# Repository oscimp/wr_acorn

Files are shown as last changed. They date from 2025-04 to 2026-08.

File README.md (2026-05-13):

# White Rabbit on general purpose FPGA boards (without the dedicated external oscillators)

Based on the original contribution by <a href="https://www.missinglinkelectronics.com/wp-content/uploads/2024/03/MLE-Light-Rabbit-Presentation-at-13th-White-Rabbit-Workshop.pdf">Missing Link Electronics</a> at the 13th White Rabbit
Workshop at CERN in 2024 and with the help of Nikhef's <a href="https://www.nikhef.nl/~peterj/">Peter Jansweijer</a>
CLBv3 (found on <a href="https://gitlab.com/ohwr/project/wr-cores/-/tree/master/syn/clbv3_ref_design?ref_type=heads">the OHWR gitlab repository</a>), this project demonstrates a functional White Rabbit implementation
on the <a href="https://enjoy-digital-shop.myshopify.com/products/litex-acorn-baseboard-mini-sqrl-acorn-cle215">Acorn CLE215+</a> Artix7 FPGA.

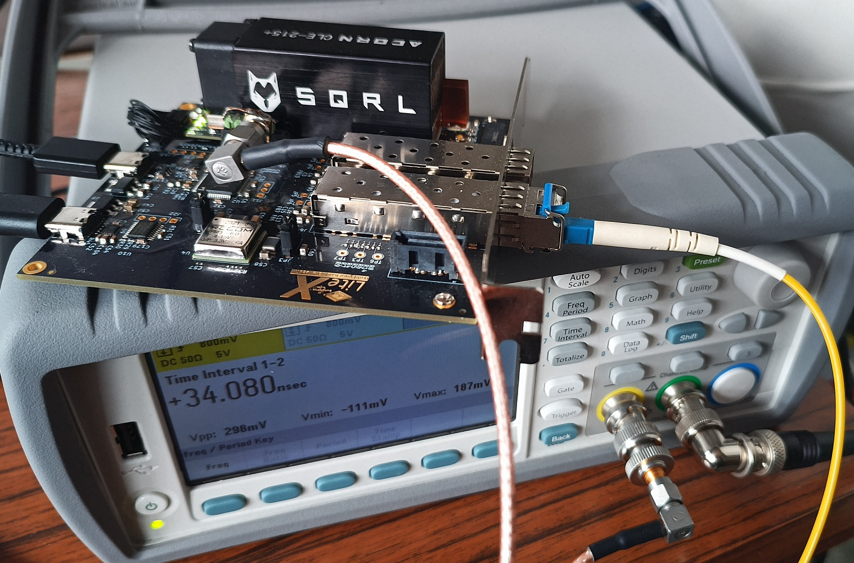
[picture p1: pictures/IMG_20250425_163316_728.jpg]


Be aware that the picture was taken in the early development stages: the current ``litex_wr_nic`` is using the other SFP on the PCIe board.

## Synthesizing for the Acorn CLE215+

The patch applied to the White Rabbit PTP Core repository allowing to synthetsize the project for the Acorn
CLE215+ as well as the instructions are found in the <a href="patch/">patch</a> repository (tested with Xilinx Vivado 2022.2).

## PLL gain settings

From the shell connected to the embdded RISC-V processor, the main PLL gain coefficients (proportional and integral) are set using the command
```
pll gain 0 0 -100 -2 12
```

and similartly for the helper PLL (any negative number will do instead of -1 as 2nd argument)
```
pll gain -1 0 -100 -2 12
```
Once both PLLs are locked, the Kp and Ki can be increased for better tracking performance.

## Results

Signals are output on the J4 header:
```
USB-C side <- GND DMTD_CLK_MON SYS_CLK_MON REF_CLK_MON 1PPS 3V3 -> SFP side
```

MDEV measurement as a function of PLL loop gain coefficients, changing Kp while
keeping Ki fixed (-2) except for two measurements, of the time interval between the 
White Rabbit Switche (WRS) and the CLE215+ 1-PPS outputs. For reference, WRS is the Modified 
Allan Deviation of the two PPS generated by two WRS (Creotech),
matching the expected value of about 60 ps jitter at 1 s integration time.

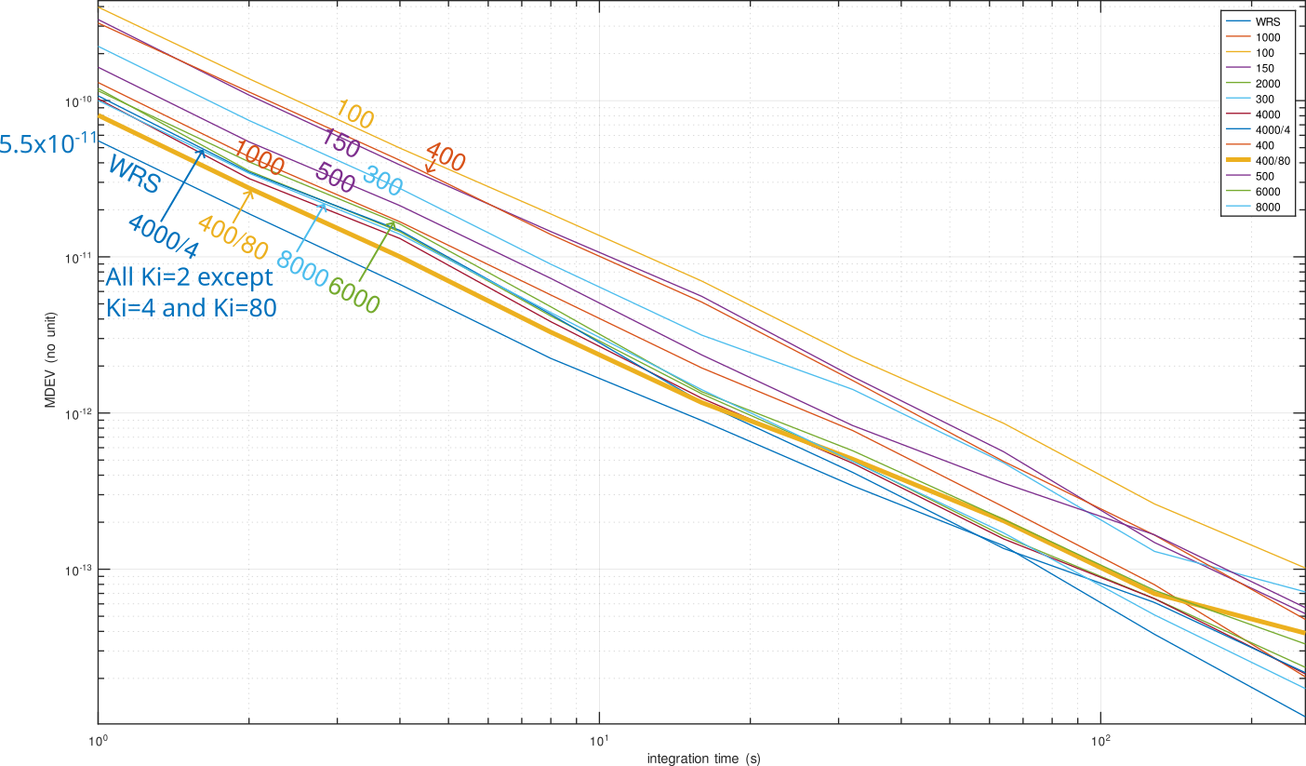
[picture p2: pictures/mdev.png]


Beyond the long-term time-domain characteristics, the phase noise of a 10-MHz output
locked on the White Rabbit control signal is measurement as a function of control loop
parameters. Measurements performed using a Rohde & Schwarz FSWP 
Phase Noise Analyzer with 10-correlations in the 1-Hz bin.



All Modified Allan deviation of the 1-PPS outputs plot exhibit a $1/\tau$ slope, i.e. $1/\tau^2$ for the variance,
characteristic of flicker phase noise. The MVAR of flicker PM [1] level is $0.0855 h_1/\tau^2$: at
1 Hz, the phase noise of $-70$ dBc/Hz or $-67$ dBrad $^2$ /Hz would lead to 
$\sqrt{10^{-6.7}/(10^7)^2\cdot 0.0855}=1.4\cdot 10^{-11}$. The observed $5.5\cdot 10^{-11}$ hints at a noise
model too simple to account for all contributions.

From this analysis, we conclude that "optimal" loop coefficients are **Kp=-4000 and Ki=-2**.

The command ``pll stat`` must display something like
```
softpll: mode:3 seq:ready n_ref 1 n_out 1
irqs:400961 alignment_state:0 HL1 ML1 HY=25714 MY=42355 DelCnt=0 setpoint:17364 refcnt:209789 tagcnt:5
```
where HL1 means that the helper PLL is locked and ML1 means that the main PLL is 
locked.

[1] E. Rubiola, *Enrico's Chart of Phase Noise and Two-Sample Variances*, https://rubiola.org/pdf-static/Enrico%27s-chart-EFTS.pdf (2025)

## SFP brands

Some SFP seem to operate properly with the Acorn, some not (but are functional with the M2SDR).

Tested as functional: Cisco GLC-BX-U BlueOptics BO15C3149620D and <a href="https://www.fs.com/fr/products/75341.html?attribute=10414&id=2101714">FS SFP-1G34-BX20</a>

Tested as **non** functional: AXCEN AXGE-1254-0531

# LiteX ``litex_wr_nic`` on Acorn

Make sure to source the Vivado ``settings64.sh`` before executing:

```
git clone --recursive https://github.com/enjoy-digital/litex_wr_nic
cd litex_wr_nic
./acorn_wr_nic.py --build
openFPGALoader -c ft4232 -b litex-acorn-baseboard-mini -f ./build/sqrl_acorn/gateware/sqrl_acorn.bin
minicom -D /dev/ttyUSB2
```

# Application to the M2SDR

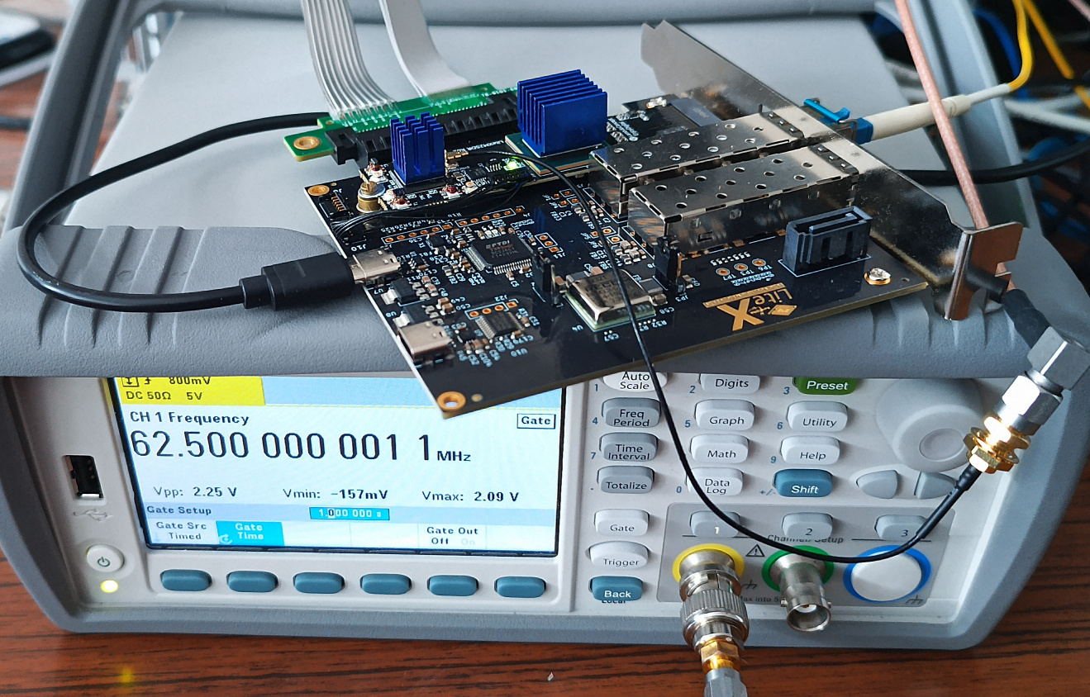
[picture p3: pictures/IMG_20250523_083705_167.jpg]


```
git clone https://github.com/enjoy-digital/litex_m2sdr
./litex_m2sdr.py --variant=baseboard --with-pcie --with-white-rabbit --with-gpio --build --eth-sfp=0 --wr-nic-dir=$HOME/litex_wr_nic/litex_wr_nic/
openFPGALoader --fpga-part xc7a200tsbg484 --cable ft4232 --freq 20000000 --write-flash --bitstream ./build/litex_m2sdr_baseboard_pcie_x1_white_rabbit/gateware/litex_m2sdr_baseboard_pcie_x1_white_rabbit.bit
```
where we manually ``openFPGALoader`` rather than ``--flash`` to synthesize and flash on different computers.

Then for communicating between PC and M2SDR: either
```
bar=`lspci | grep Xil | cut -d\  -f1`
litex_server --pcie --pcie-bar $bar
```
and then 
```
litex_term crossover --csr-csv csr.csv
```
where ``csr.csv`` was found in the ``test/`` of ``litex_wr_nic`` after synthesis of the gateware, but the
resulting terminal can hardly display the ``gui`` output of the White Rabbit, so the preferred method is
to compile the ``litex_wr_nic/software/kernel`` modules and
```
sudo insmod m2sdr.ko
minicom -D /dev/ttyLXU0
```
The WR clock output is measured using a frequency counter by adding in ``litex_wr_nic/m2sdr_wr_nic.py`` the signal ``self.comb += platform.request("sync_clk_in").eq(ClockSignal("wr"))``
as the last instruction of the ``__init()__`` function just before the ``main():``, after commenting ``platform.request("pps_out").eq(pps),`` to avoid a conflict on the SYNCDBG_CLK pin.

When loading a new gateware, the computer must usually be rebooted. Sometimes disabling the PCI board, flashing the FPGA, and then enumerated again using
```
bar=`lspci | grep Xil | cut -d\  -f1`
echo 1 > /sys/bus/pci/devices/0000:$bar/remove
openFPGALoader -c ft4232 -b litex-acorn-baseboard-mini -f gateware.bit
echo 1 > /sys/bus/pci/rescan
```
and then ``rmmod`` and ``insmod`` the ``m2sdr.ko`` module might succeed (or fail).

**Note**: in case ``from litex_m2sdr import Platform`` fails when synthesizing the m2sdr branch of https://github.com/enjoy-digital/litex_wr_nic, make sure to
```
pip install --user -e .
```
in the litex_m2sdr repository.

**Note**: ``m2sdr_wr_nic.py --build`` synthesis fails with Vivado 2019.2 or 2020.1 and *succeeds* with Vivado 2022.2.

## Results

Phase noise (M2SDR scaled 62.5-MHz v.s White Rabbit switch 10-MHz output):



Allan deviation:

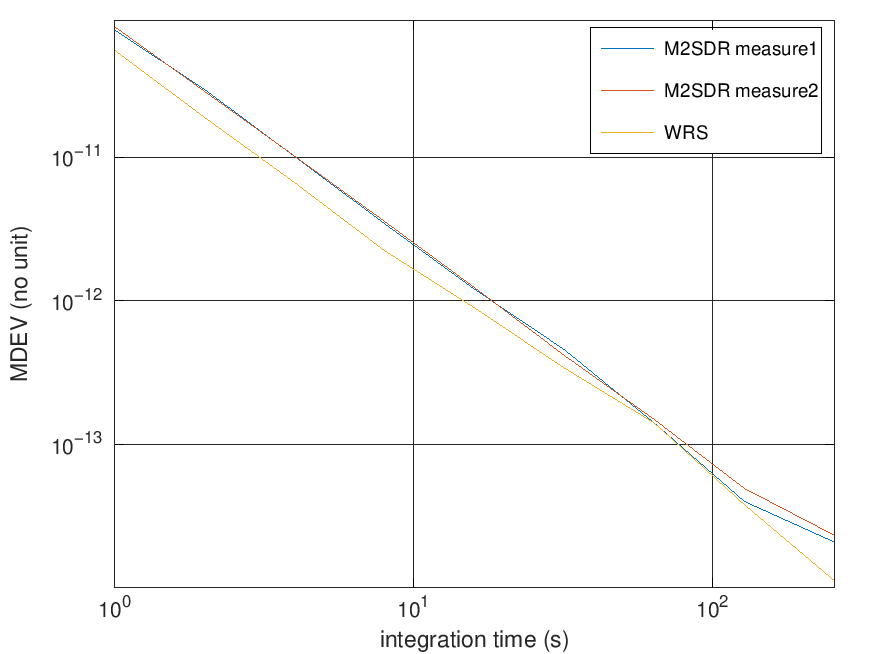
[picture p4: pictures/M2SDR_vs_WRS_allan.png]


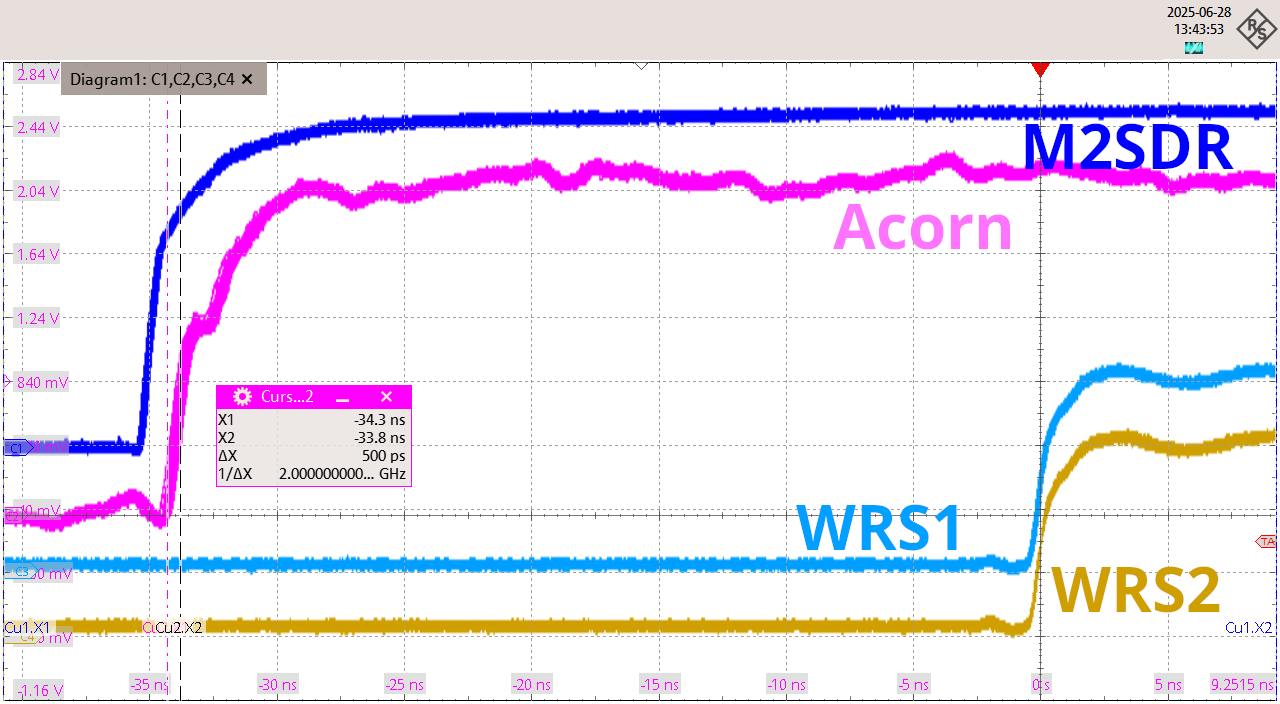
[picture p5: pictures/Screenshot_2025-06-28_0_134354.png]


## M2SDR SDR with WR support

In ``litex_m2sdr``, assuming ``litex_wr_nic`` is at the same filesystem tree level (possibly update ``litex_m2sdr.py`` with the two 
``FIXME: Avoid harcoded path/platform`` directory information accordingly for different tree structure) and was installed using 
``pip install --user -e .``:
```
./litex_m2sdr.py --variant=baseboard --with-pcie --with-white-rabbit --build
```
on the build computer running Vivado (in our case 2022.2), and then on the target computer the PCIe with the M2SDR board is connected to:
```
openFPGALoader --fpga-part xc7a200tsbg484 --cable ft4232 --freq 20000000 --write-flash --bitstream ./build/litex_m2sdr_baseboard_pcie_x1_white_rabbit/gateware/litex_m2sdr_baseboard_pcie_x1_white_rabbit.bin
sudo echo 1 > /sys/bus/pci/rescan
```
Then from a kernel module perspective, ``scp -r litex_m2sdr/software/`` from the build computer to the target computer and in ``software/kernel`` run ``make`` to
compile the kernel modules, leading to ``m2sdr.ko`` and ``liteuart.ko``. Once these two kernel modules are loaded
```
sudo insmod m2sdr.ko
sudo insmod liteuart.ko
```
the communication interface ``/dev/ttyLXU0`` is created and ``minicom -D /dev/ttyLXU0`` displays a prompt
```
wrc# ver                                                                                        
WR Core build: wrpc-v5.0-ohwr-9-g5ac04dd5-dirt (unsupported developer build)
Built: Jul 18 2025 08:28:12 by JM Friedt
Built for RISCV, 128 kB RAM, stack is 2048 bytes
```

**DO NOT** attempt to use the kernel modules found in ``litex_wr_nic``: despite similar names, they will kernel panic. Also make sure to
**recompile** the kernel according to the new gateware configuration since header files ``csr.h``, ``mem.h`` and ``soc.h`` are automagically 
generated during gateware synthesis, so
that kernel modules must be recompiled accordingly on the target computer.

**Major update**: notice that many of the screenshots display ``wrpc-v5.0`` as this was the
version initially shipped with ``litex_wr_nic``. This version was replaced with the
newer (and latest at the time) v8 end of Feb. 2026. From now on, the release version (``ver``)
displays ``WR Core build: v8.0-126-gbaf77496-dirty (unsupported developer build)``.

Result: phase-lock of the M2SDR with SDR capability on the WR switch master signal
```
SAWR WRPC Monitor wrpc-v5.0-ohwr-9-g5ac04dd5-dirt | Esc/q = exit; r = redraw

TAI Time: 2023-05-12-12:28:06  UTC offset: 37   PLL mode: BC  state: Locked 
---+-------------------+-------------------------+---------+---------+-----
 # |        MAC        |       IP (source)       |    RX   |    TX   | VLAN
---+-------------------+-------------------------+---------+---------+-----
 0 | 22:33:44:55:66:77 |                         |    3105 |    1291 |    0

--- HAL ---|------------- PPSI ------------------------------------------------
 Itf | Frq |  Config   | MAC of peer port  |    PTP/EXT/PDETECT States   | Pro 
-----+-----+-----------+-------------------+-----------------------------+-----
 wr0 | Lck | auto      | 70:b3:d5:91:ea:f0 | SLAVE    /IDLE      /EXT_ON | R-W 
Pro(tocol): R-RawEth, V-VLAN, U-UDP

--------------------------- Synchronization status ----------------------------
Servo state:          White-Rabbit: TRACK_PHASE                         

--- Timing parameters ---------------------------------------------------------
meanDelay        :              285.439 ns
delayMS          :              285.439 ns 
delayMM          :             1095.745 ns 
delayAsymmetry   :                0.000 ns
delayCoefficient :   +0.000000000000000000  fpa   0
ingressLatency   :                0.000 ns
egressLatency    :                0.000 ns
semistaticLatency:                6.400 ns
offsetFromMaster :               -0.025 ns
Phase setpoint   :                1.548 ns
Skew             :                0.067 ns
Update counter   :                  626 times
Master PHY delays TX:               238.809 ns   RX:           279.657 ns 
Slave  PHY delays TX:                 0.000 ns   RX:             6.400 ns 
```

If the finite state machine remains in ``Servo state:          White-Rabbit: SYNC_PHASE           (wait for hw)`` then
execute ``ptrack ps-freeze``.

## WR clock output for phase noise measurement
To output the 62.5 MHz WR disciplined clock on the WFL output, comment https://github.com/enjoy-digital/litex_m2sdr/blob/main/litex_m2sdr.py#L522C1-L528C60
```
self.gpio.connect_to_pads(pads=platform.request("gpios"))

# Drive led from GPIO0 when in loopback mode to ease test/verification.
self.sync += If(self.gpio._control.fields.loopback, led_pad.eq(self.gpio.i_async[0]))

# Use GPIO0 as ClkIn.
self.comb += si5351_clk_in.eq(self.gpio.i_async[0])
```
and replace with
```
self.comb += platform.request('debug').eq(ClockSignal('wr'))
```
## Changing the beatnote frequency
To change the beatnote from $62.5*(1-2^{14}/(2^{14}+1))=3814$ Hz, update the content of ``litex_wr_nic/firmware/wrpc-sw/include/spll_defs.h`` where ``HPLL_N`` is defined with the default value of 14.

## Firmware update without gateware generation

``litex_wr_nic`` provides, in the ``test`` directory, the ``test_cpu.py`` script which allows uploading the firmware without generating the full gateware.

1. Install ``litex_wr_nic`` by running ``pip install --user -e .`` in the git cloned <a href="https://github.com/enjoy-digital/litex_wr_nic">litex_wr_nic</a> directory
2. In the git cloned <a href="https://github.com/enjoy-digital/litex_m2sdr">litex_m2sdr</a> directory, synthesize the gateware (requires Vivado and litex standard install):
```
./litex_m2sdr.py --variant=baseboard --with-pcie --with-white-rabbit --build
cp csr.csv ../litex_wr_nic/test/
openFPGALoader --fpga-part xc7a200tsbg484 --cable ft4232 --freq 20000000 --write-flash --bitstream ./build/litex_m2sdr_baseboard_pcie_x1_white_rabbit/gateware/litex_m2sdr_baseboard_pcie_x1_white_rabbit.bin
# probably need to shutdown and restart the computer as the PCIe bus might be corrupt when rescanning the PCI bus after gateware upload
cd litex_m2sdr/software/kernel
make
sudo insmod m2sdr.ko
```
resulting in ``dmesg`` with
```
m2sdr 0000:06:00.0: Version LiteX-M2SDR SoC / baseboard variant / built on 2025-09-04 12:41:57
```
and at this point executing ``minicom -D /dev/ttyLXU0`` allows for
```
wrc# ver                                                                                              
WR Core build: wrpc-v5.0-ohwr-9-g5ac04dd5-dirt (unsupported developer build)
```

When using the M2SDR on a different computer than the one used for the synthesis, we need to ``scp`` the ``litex_m2_sdr/software/kernel`` and ``csr.csv`` to the remote computer, as well as ``litex_wr_nic/firmware/wrpc-sw/wrc.bin``.

3. <del>execute ``litex_server --jtag --jtag-config=openocd_xc7_ft4232.cfg`` in one terminal or one screen session</del>
At the moment ``litex_server --jtag`` does not seem functional for transfering the gateware through JTAG so we
```
sudo insmod m2sdr.ko  # if not already loaded, e.g. on a remote computer
bar=`lspci | grep Xil | cut -d\  -f1`
sudo chmod -R 777 /sys/bus/pci/devices/0000\:$bar
litex_server --pcie --pcie-bar $bar
```
Notice that ``m2sdr.ko`` must be loaded to allow executing ``litex_server``. Notice that an ``Invalid argument: mmap`` might be solved by <a href="https://stackoverflow.com/questions/18420473/invalid-argument-for-read-write-mmap">adding</a> ``iomem=relaxed`` to the kernel boot options.

5. Now that we have the ``csr.csv`` memory configuration file in the ``litex_wr_nic/test`` directory (see step 2), go there and
```
cd ../litex_wr_nic/test
./test_cpu.py --build-firmware
./test_cpu.py --load-firmware ../litex_wr_nic/firmware/wrpc-sw/wrc.bin
minicom -D /dev/ttyLXU0
```
Make sure to **remove** lines 72-73 which execute a ``git checkout`` in ``firmware/build.py`` that would delete all updates made on the ``spll_main.c`` firmware file

## Communication with the SFP

Baptiste Marechal notices that I2C communication is through JP1 and JP4 (or JP5/JP6 for the
second SFP) which are not closed on the PCI baseboard

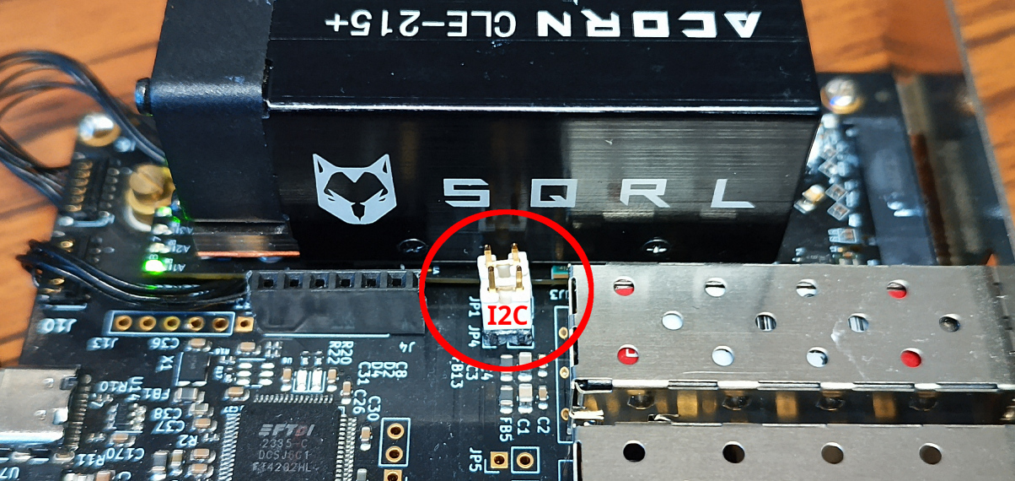
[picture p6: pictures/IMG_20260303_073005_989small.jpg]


Thanks to this connection
```
wrc# sfp info                                                                   
Nominal Bit Rate: 1300 Mbits/s
Vendor Name: FS              
Vendor PN: SFP-GE-BX                                                            
Vendor serial: G2440324549                                                      
TX Wavelength: 1310                                                             
Temperature: 34.41 C                                                            
Voltage: 3.3029 V                                                               
Bias Current: 9.00 mA                                                           
TX power: 0.2481 mW                                                             
RX power: 0.2520 mW                                                             
```
instead of 
```
wrc# sfp info                                                                   
Nominal Bit Rate: 25500 Mbits/s
Vendor Name: ����������������
Vendor PN: ����������������
Vendor serial: ����������������
TX Wavelength: 65535
Temperature: 255.99 C
Voltage: 6.5535 V
Bias Current: 131.07 mA
TX power: 6.5535 mW
RX power: 6.5535 mW
```
when the jumpers are not closed.

## Reading the FPGA die temperature

LiteX implements the <a href="https://github.com/enjoy-digital/litex/issues/1257">XADC</a> FPGA die temperature measurement, exposed in the CSR at register location 8192 or 0x2000. Hence
```
m2sdr_util reg-read 0x2000 | cut -dx -f3
```
reads the 12 bit XADC register whose value is converted to degC according to <a href="https://docs.amd.com/r/en-US/ug480_7Series_XADC/Analog-Inputs">this AMD manual</a>. The temperature reading is automated with
```
#!/usr/bin/bash
while true; do
   d=`date +%s`
   t=$(echo $((16#$(m2sdr_util reg-read 0x2000 | cut -dx -f3)))*503.975/4096-273.15 | bc)
   echo $d $t
   sleep 10
done
```

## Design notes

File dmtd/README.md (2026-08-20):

# DMTD isolated design for qualifying the phase detector

This repository provides a gateware for synthesizing an Amaranth implementation
of the <a href="https://white-rabbit.web.cern.ch/documents/White_Rabbit_Clock_Characteristics.pdf">DDMTD</a> for the Digilent Cmod-A7 board as described at
https://github.com/oscimp/amaranth_twstft/tree/main/pcb/cmodA7_twtft

This PCB includes one comparator converting the incoming clock signal to a square
wave (to pin 46), so that a second external comparator is needed to clock the second SMA 
located after the one connected to the SAW filter (pin 36). The DMTD phase comparator 
output is found on the SMA between the two clock inputs (pin 42). The output can
be fed to a phase noise analyzer or oscilloscope for statistical analysis of the
DMTD output.

## Digital Mixer Time Difference

The DMTD function is to measure fine timing of digital clocks. It does so by (sub)sampling the input clock with a frequency shifted clock to time-strech the input clock into a low-frequency signal which can be measured with a great resolution relative to its period, the output of the DMTD is a flow of time stamps (phase tags) of the stretched rising edges.

The *D*DMTD uses two DMTDs and takes the difference of the phase tags to output the relative phase of two clocks:

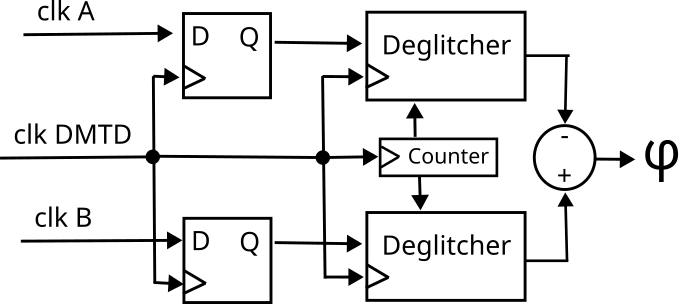
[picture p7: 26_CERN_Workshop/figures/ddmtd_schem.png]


Here, to study this DDMTD phase meter we first focus on the simpler DMTD.

### Notations

The frequency ratio between the measured clock and the sampling clock (also called pivot or DMTD helper clock) is set as $2^N/(2^N - 1)$ with $N = 14$ unless specified otherwise.

This means that the frequency difference (named beatnote) is $1/2^N$ times the measured clock frequency. This beatnote also corresponds to the output rate the DMTD.

The output phase tags counts time in cycles of the pivot clock, in a noiseless systeme, they are each spaced of $2^N$ cycles.

The phase resolution is then of $N$ bits.

For example when measuring a 62.5 MHz clock with $N=14$, we get phase tags at the rate of $62.5e6/2^{14}=3.814$ kHz with a resolution of $16\cdot 10^{-9}/2^{14}\simeq 1$ ps.

## Aliasing

Since the DMTD is subsampling the input clock, it aliases high frequency noise in the small bandwith of it's low-frequency output (1.9 kHz bandwith in default White Rabbit).

This can be demonstrated by feeding a clock with a single spure of noise at a variable offset frequency and observing how this spur is folded into the dmtd's output:

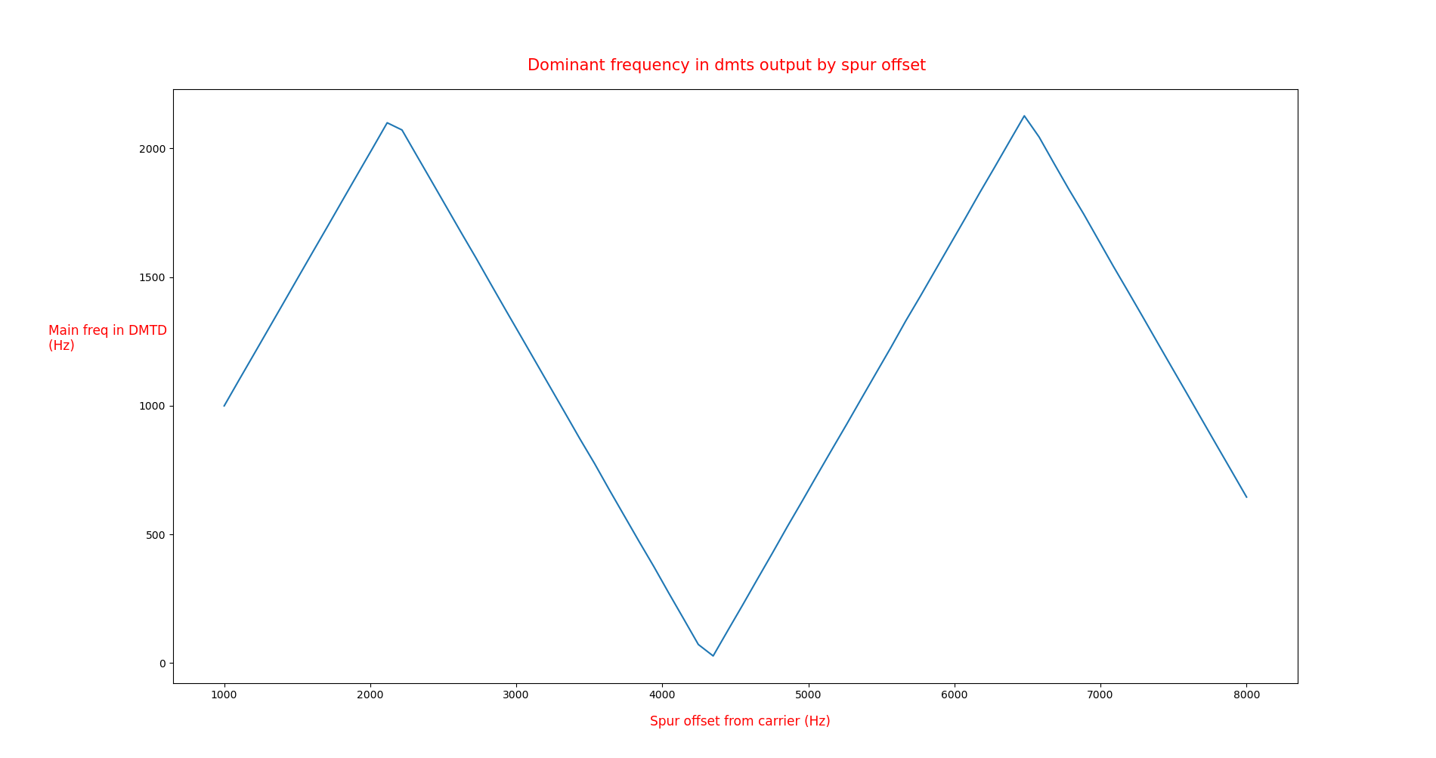
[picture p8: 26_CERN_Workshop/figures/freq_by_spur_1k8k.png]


frequency of the spur on the output in function of its frequency at the input

This hints that all the noise is conserved and folded ($2^N$ times) in the DMTD's bandwith leading to a $2^N$ times higher floor noise with the same noise power.

We observe that it is, in fact, not the case: by feeding the DMTD a clock with white gaussian phase noise and measuring the noise at the output we get this square root response:

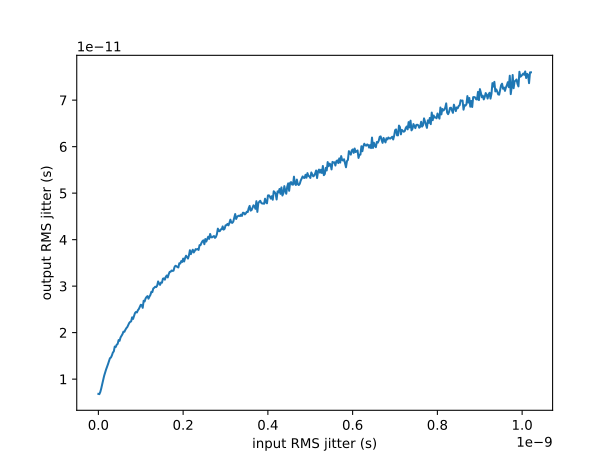
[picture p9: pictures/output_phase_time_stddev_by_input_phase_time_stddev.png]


DMTD stddev at the output in function of the stddev at the input

This nonlinear behavior cannot be explained by the (linear) sampling, this suggests there is a non-linear filtering action of the deglitcher.

## Glitches

Because of clocks jitter and/or metastabilities (we have yet to investigate which is dominant and wether they have distinct effects), the output of the sampling flip-flop contains many transitions for each ideal streched clock transitions.



ILA capture of the sampled clock.

The deglitcher process this waveform and computes the phase tag of the true transition. Multiple deglitchers algorithms have been proposed and evaluated ([Tom's thesis](https://gitlab.com/ohwr/project/white-rabbit/-/wikis/uploads/6a357829064b9e27a46fbce4cb4398b4/mgr.pdf)) empiricaly we find that the "bit median" produce the less noisy outputs but we lack a rigorous understanding of why.

The bit median deglitcher assumes that the glitches are like random independant "flip" errors on the true clean rising edge of the streched clock, following some constant (over time) distribution around this true rising edge.
It then compute and output the phase tag such that there is as many "up" glitches before the phase tag as "down" glitches after the phase tag.
This is exactly the same as a doing least square fit of the glitched signal with the ideal step and outputting the time of the fitted step's rising edge.
This kind of fit can be realized in many ways: this bit median / cross-correlation / convolution, these are all the same computation, of which the "bit median" algorithm is just a very efficient FPGA implementation. 

The length of this glitchy window is directly proportional to the input clock jitter:

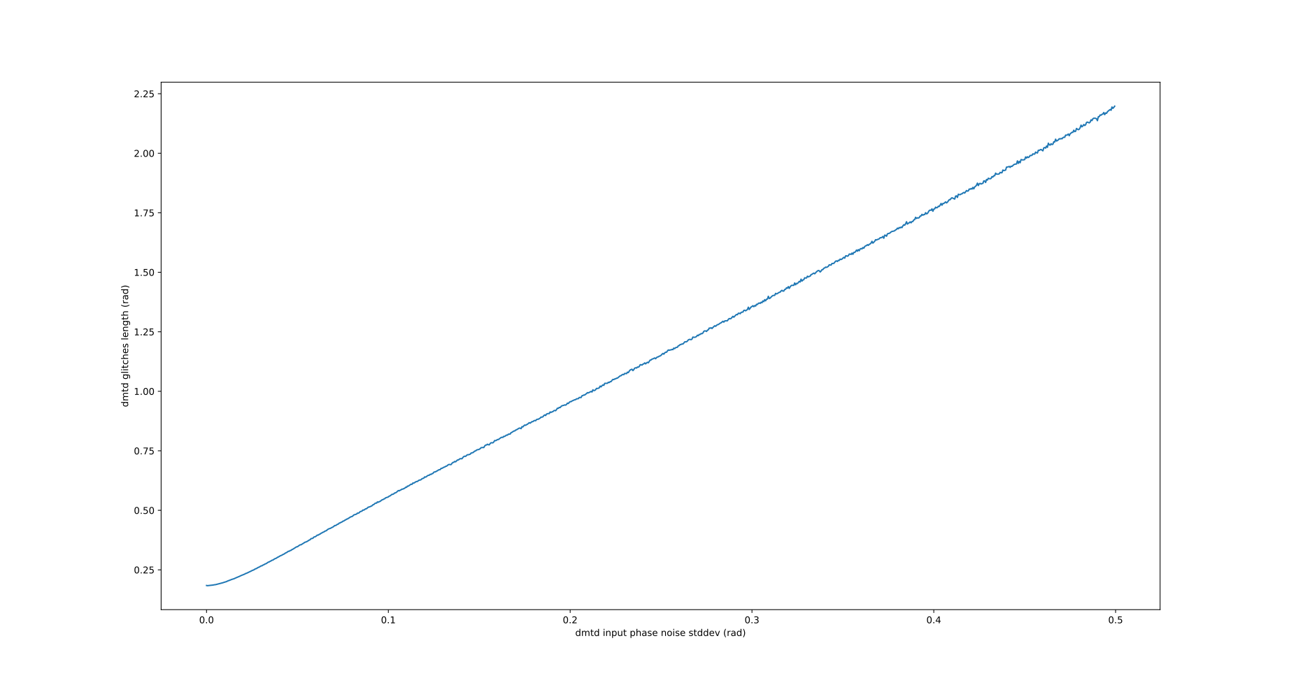
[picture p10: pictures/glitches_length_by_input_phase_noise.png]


DMTD average gltiches length is proportional to input jitter

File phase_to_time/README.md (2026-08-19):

## Compute the time jitter from a phase noise spectrum in dBc/Hz.

Result: 36 ps when integrating to 10 MHz without weighing function, 25 ps with the sin^2 weighing function accounting
for the discrete time sampling of the 1-PPS.

## Compute the Allan deviation from a phase noise spectrum in dBc/Hz.

See <a href="https://rubiola.org/pdf-lectures/Scientific%20Instruments%20L06-10,%20Oscillators.pdf">Enrico Rubiola's lecture</a>, slides 6 and 48-52 for the 
Phase Noise to Allan Deviation conversion explanation, and which $H(f)$ filter
function to use depending on the targeted deviation (Allan, Modified or Hadamard).

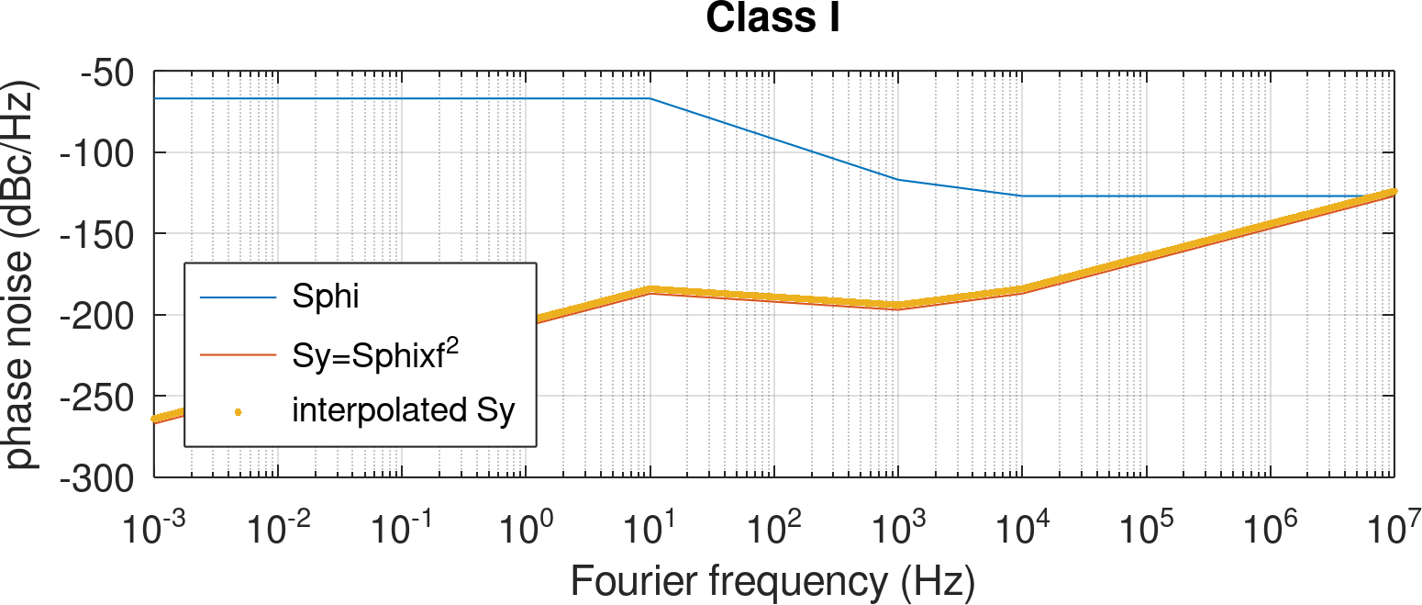
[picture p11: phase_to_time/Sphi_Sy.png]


Phase noise

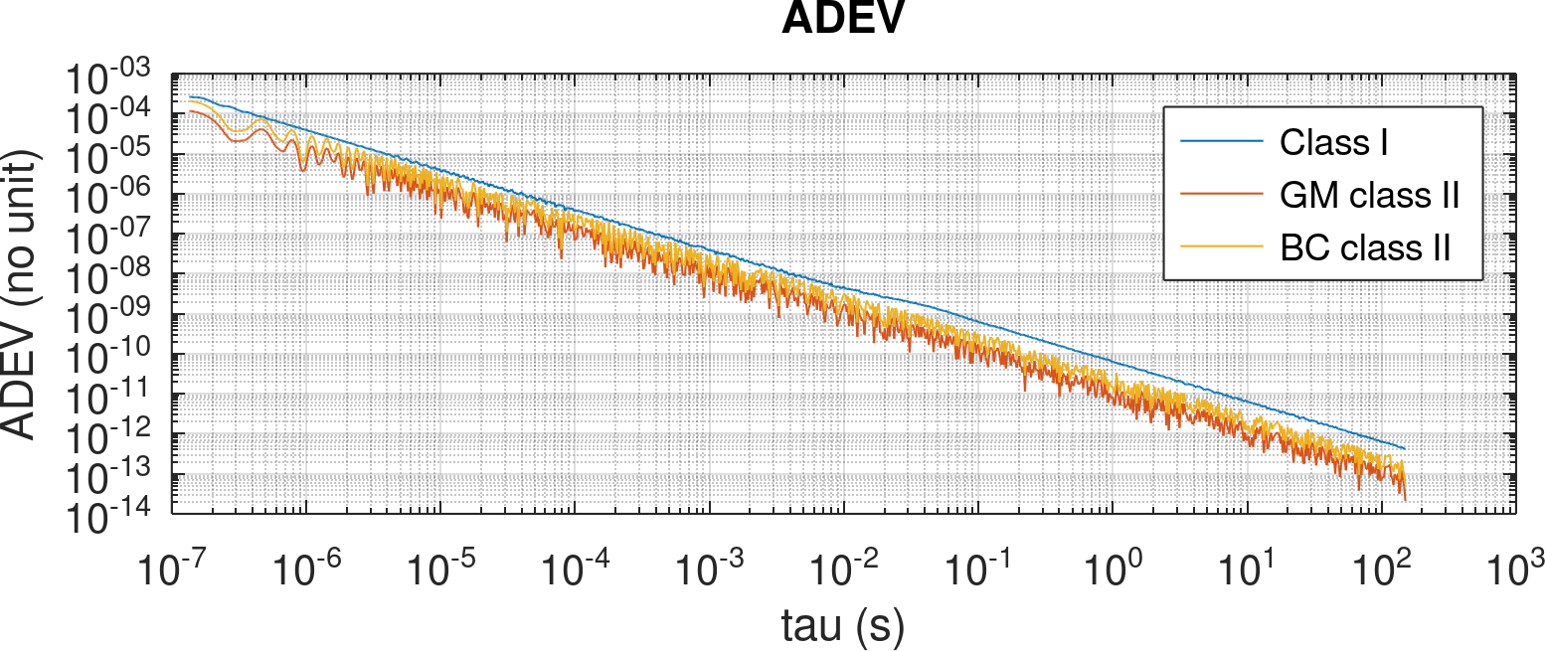
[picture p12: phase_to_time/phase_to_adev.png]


Resulting ADEV

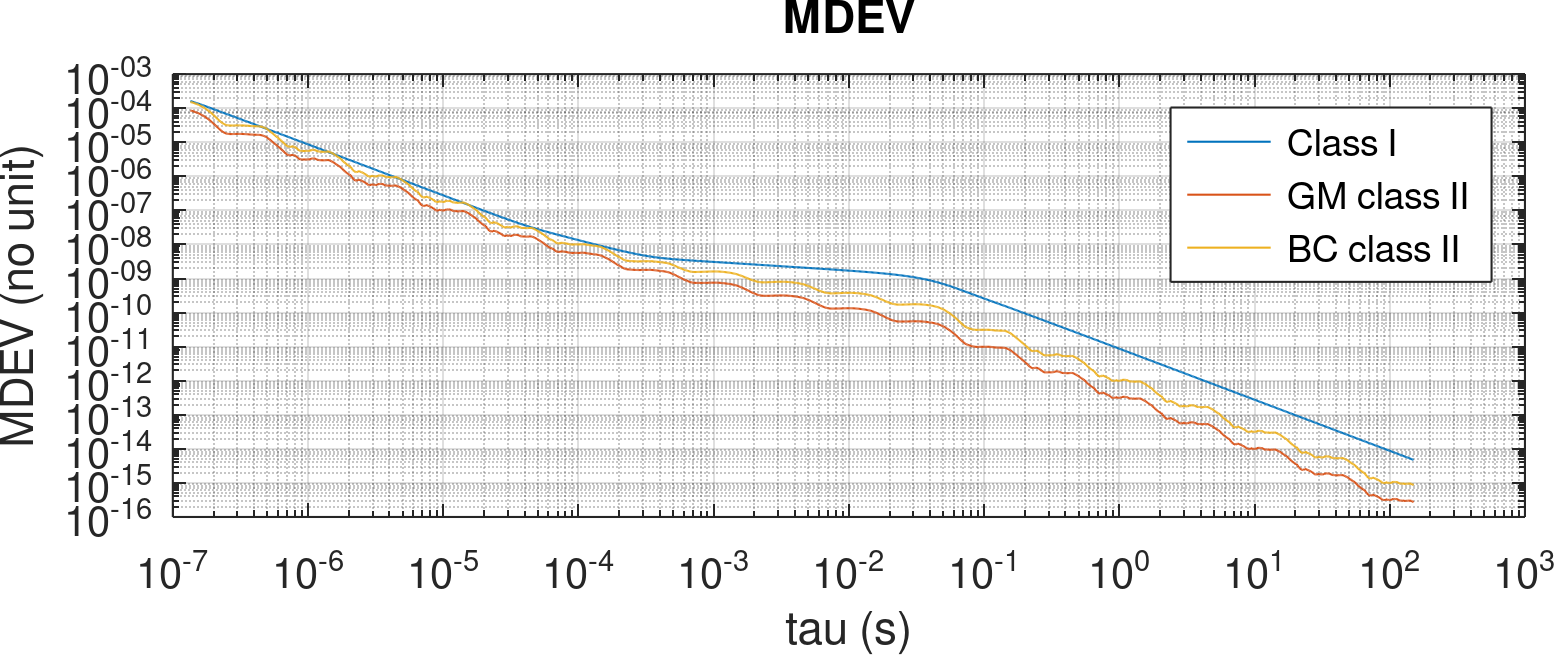
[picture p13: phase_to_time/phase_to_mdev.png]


Resulting MDEV

These scripts were used for analyzing some of the information shared
in <a href="https://www.white-rabbit.tech/wp-content/uploads/2025/12/WR_Requirements_v1.0.0.pdf">the White Rabbit requirements.</a>

## Compute the decoherence from a phase noise spectrum in dBc/Hz.

Using some "realistic" values from the <a href="https://abracon.com/phase-noise-and-jitter-calculator#">Abracon oscillator phase noise calculator</a>.

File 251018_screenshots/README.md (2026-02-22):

## Validation of ``wr_acorn``, ``litex_wr_nic`` and ``litex_m2sdr`` running White Rabbit

* ``wr_acorn`` and ``litex_wr_nic`` are both functional, but the
state machine must be understood in detail to properly reach phase lock.

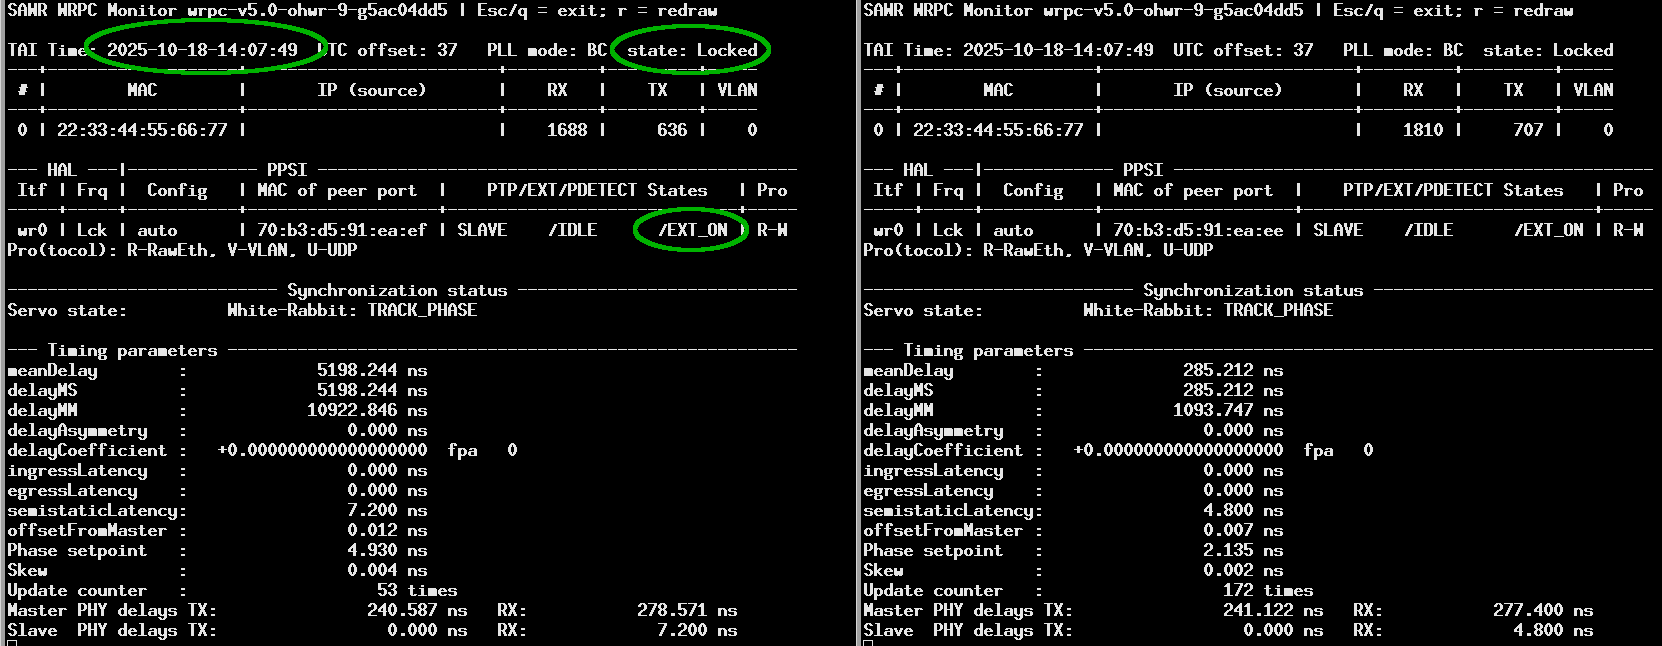
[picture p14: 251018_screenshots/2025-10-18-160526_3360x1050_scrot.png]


This screenshot demonstrates the targeted result, namely ``TRACK_PHASE`` on 
two M2SDR boards connected to a White Rabbit master. We have concluded that
* if ``EXT_ON`` switches to ``EXT_OFF`` state, the lock can never be reached.
If the ``EXT_OFF`` state is reached before the phase is ``Locked`` (ie remains
``Locking``), then
```
ptp stop
ptp start
```
to restart the locking procedure. The proportional and integral coefficients,
Kp and Ki, are kept when restarting the lock.
* at startup, the Kp and Ki values are too large, especially with ``wr_acorn``
which uses the default ``wrpc_sw`` values of -1100 et -30. To change these values,
```
pll gain 0 0 -100 -2 12
pll gain -1 0 -100 -2 12
```
to switch the main (0 0) and helper (-1 0) PLL coefficients to -100 and -2. However,
the state machine sometimes returns these coefficients to their default value, so that
we constantly monitor the PLL state with
```
pll stat
```
and reprogram the Kp and Ki to our setpoints if changed. This sequence is shown in

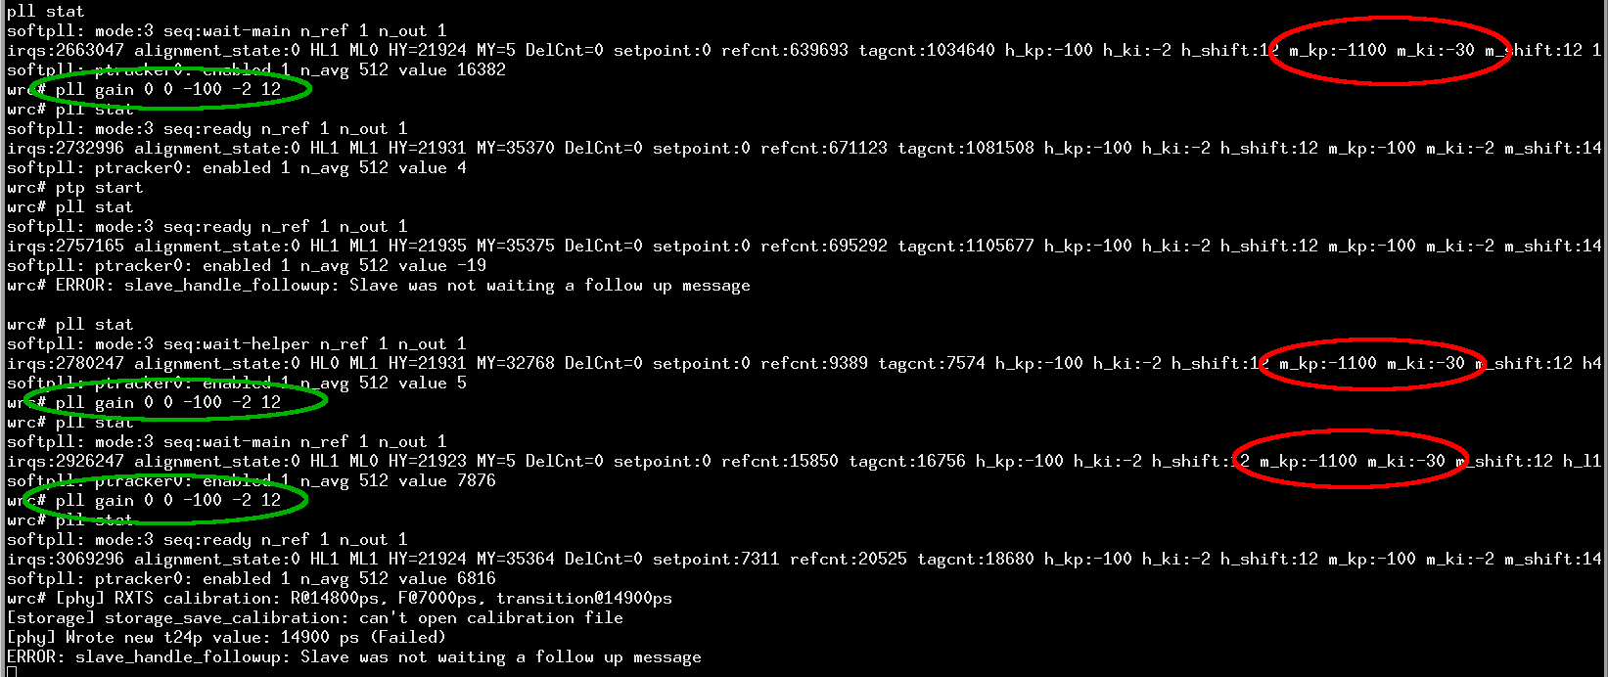
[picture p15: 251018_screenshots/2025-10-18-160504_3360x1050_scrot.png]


Both PLLs are locked if ``HL=1`` and ``ML=1``, but only the last message ending with
``(Failed)`` indicates that phase lock was achieved. Once locked, the Phase Lock state remains
as shown in

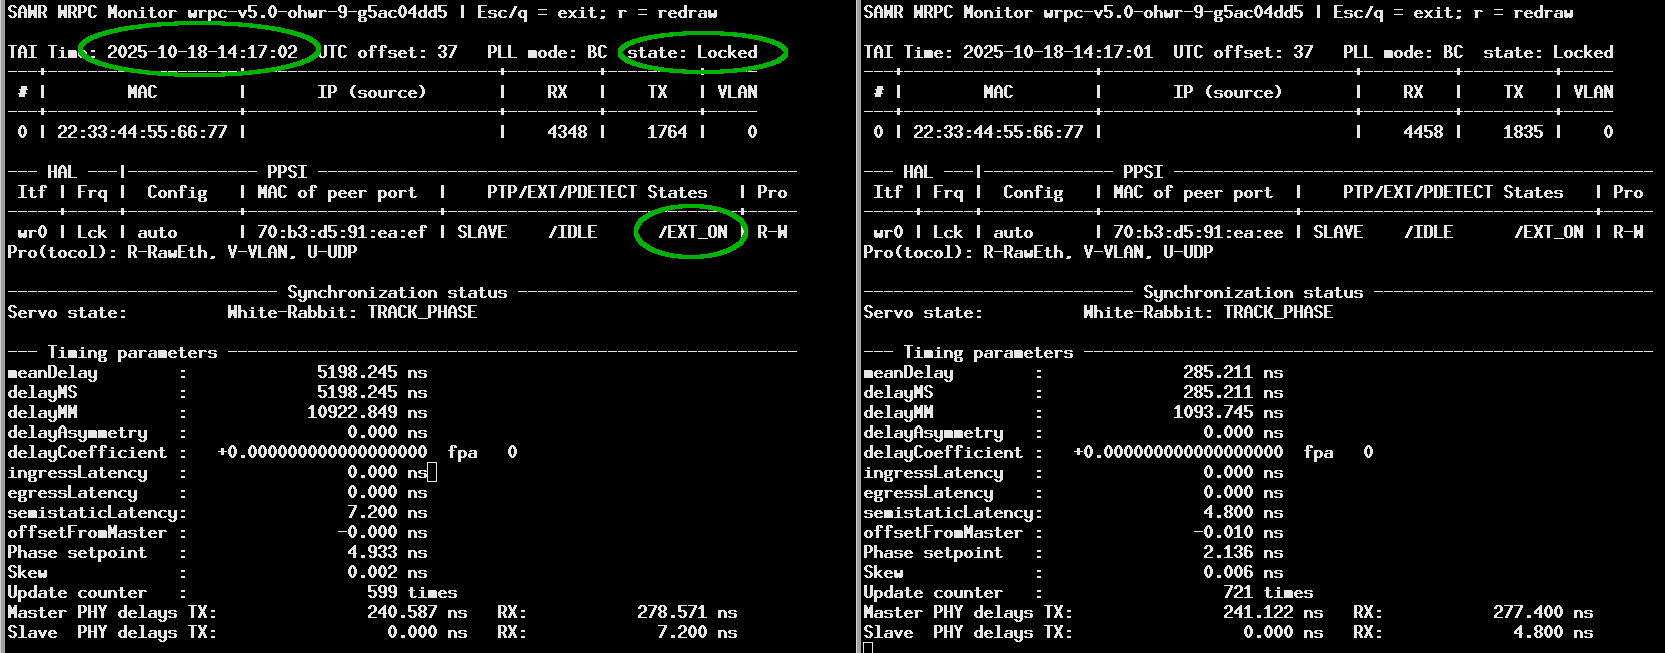
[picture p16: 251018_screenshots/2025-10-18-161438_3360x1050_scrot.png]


saved 10 minutes later, and possibly some more agressive Kp and Ki could be used to improve tracking
capability.

Additionnally, the MAC address is the same for both M2SDR in this demonstration and yet does not
prevent WR lock. However, manually changing the MAC so that each board
has a different identifier might be desirable, at least for data transfer.
* firwmare programming through the PCIe bus: we have observed that when a terminal freezes, it is due
to an errouneous firmware transfer, as shown with the dump using ``test_cpu.py --dump-firmware``. We
have observed that 3 out of 4 bytes are null, leading to inconsistent opcodes that cannot be executed
by the softcore. Looking at the BIOS settings of the computer used in these tests, the initial
configuration with one board failing to be programmed is

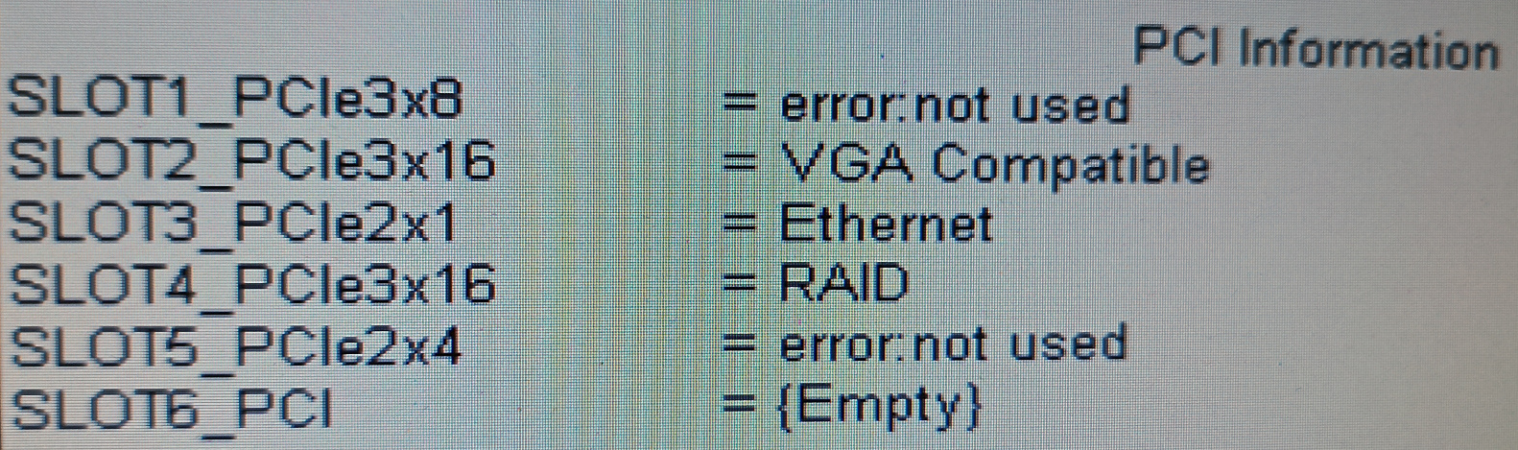
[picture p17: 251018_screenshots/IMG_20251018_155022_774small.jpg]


where the two ``not used`` slots are fitted with M2SDR boards on PCIe adapters. Since
``dmidecode`` indicates ``Length: Short`` for the (bottom) functional board but
``Length: Long`` for the (top) non-functional board, we have switched the Ethernet board
on the PCI2x1 slot and the M2SDR on the PCI3x8 slot, leading to the following configuration:

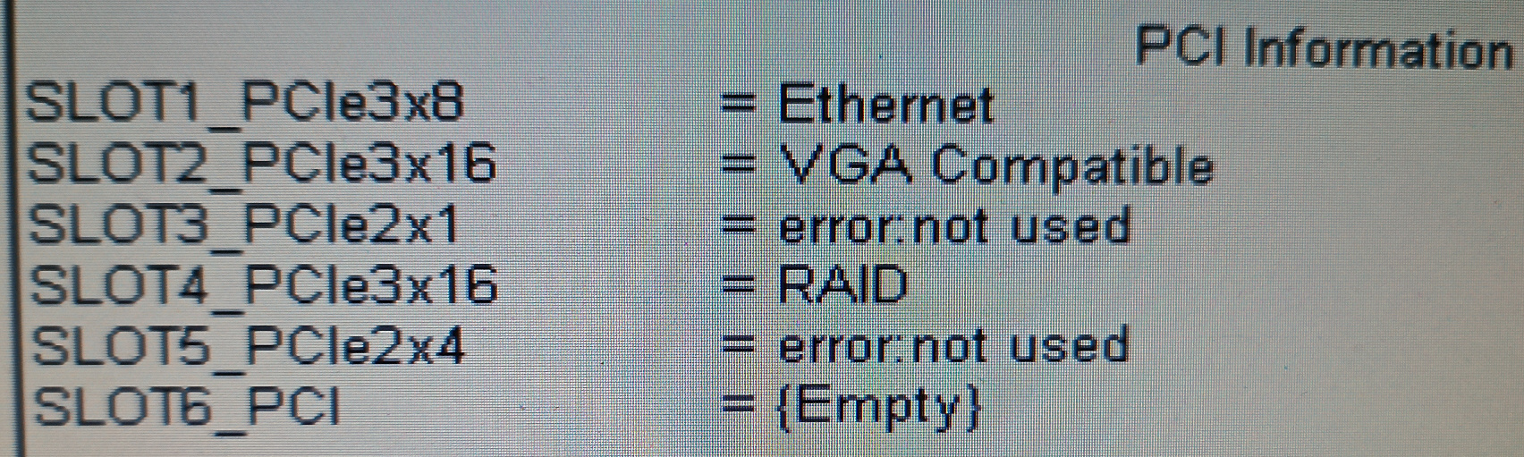
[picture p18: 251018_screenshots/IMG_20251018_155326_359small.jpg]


in which both board firmware could be programmed by ``test_cpu.py`` through the PCIe bus,
leading to functional phase locks on the White Rabbit master as shown earlier.
* at the moment, streaming the data from two M2SDR boards to GNU Radio with two SoapySDR Custom
source blocks seems not functional. By using the ``path=/dev/m2sdrX`` driver option (instead 
of ``device=X``) with X=0 or 1, then we avoid the error of the source already being opened
but the flowchart fails with error -8

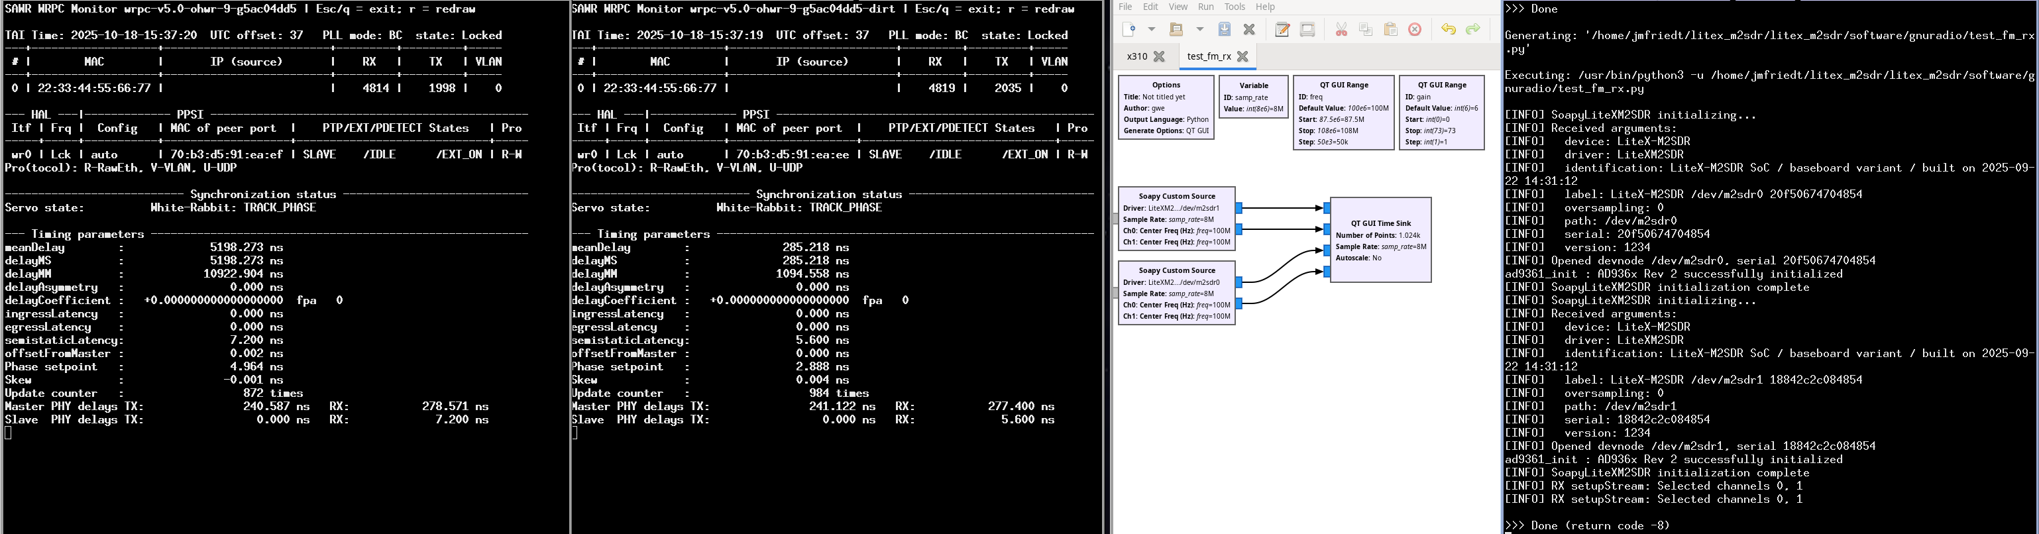
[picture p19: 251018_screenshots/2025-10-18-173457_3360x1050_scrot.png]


whereas each individual board is operating properly when streaming individually.

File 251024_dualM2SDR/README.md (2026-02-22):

# White Rabbit on general purpose FPGA boards (without the dedicated external oscillators)

Starting from a setup where both White Rabbit are locked:

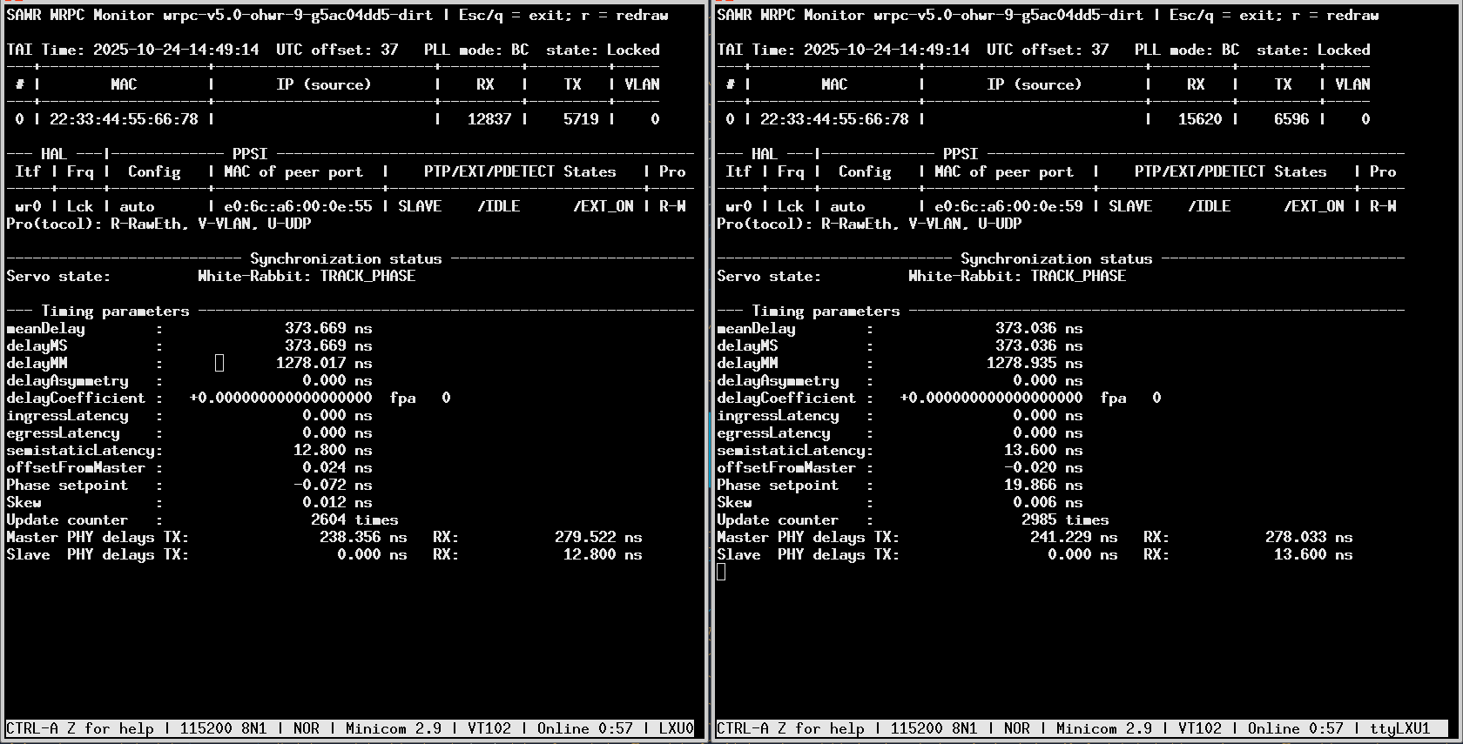
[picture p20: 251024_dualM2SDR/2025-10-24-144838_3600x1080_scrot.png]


we configure the M2SDR for external clock synchronization (i.e. locking the Si5351 to the 10 MHz WR output)

```
sudo ./m2sdr_rf -c 0 -sync white-rabbit -rx_freq 100000000 -rx_gain 20 -samplerate 8000000
sudo ./m2sdr_rf -c 1 -sync white-rabbit -rx_freq 100000000 -rx_gain 20 -samplerate 8000000
```
with each command answering with messages such as
```
litex_m2sdr/litex_m2sdr/software/user$ sudo ./m2sdr_rf -c 0 -sync internal -rx_freq 100000000 -rx_gain 20 -samplerate 8000000
Initializing SI5351 Clocking...
Using internal XO as SI5351 RefClk...
Initializing AD9361 SPI...
Initializing AD9361 RFIC...
Setting Channel Mode to 2T2R.
ad9361_init : AD936x Rev 2 successfully initialized
Setting TX/RX Samplerate to 8.000000 MSPS.
Setting TX/RX Bandwidth to 56.000000 MHz.
Setting TX LO Freq to 2400.000000 MHz.
Setting RX LO Freq to 100.000000 MHz.
Setting TX Gain to -20 dB.
Setting RX Gain to 20 dB.
Setting Loopback to 0
Enabling 16-bit mode.
```

Then record a dataset from
```
sudo ./m2sdr_record -c 0 /tmp/0.bin 800000 & sudo ./m2sdr_record -c 1 /tmp/1.bin 800000
```
and in GNU Octave (see <a href="go.m">go.m"</a>):
```
f=fopen('/tmp/0.bin');
d=fread(f,inf,'int16');d=d(1:2:end)+j*d(2:2:end);d1=d(1:2:end);d2=d(2:2:end);
plot(real(d1))
f=fopen('/tmp/1.bin');
d=fread(f,inf,'int16');d=d(1:2:end)+j*d(2:2:end);d1=d(1:2:end);d2=d(2:2:end);
plot(real(d1))
```

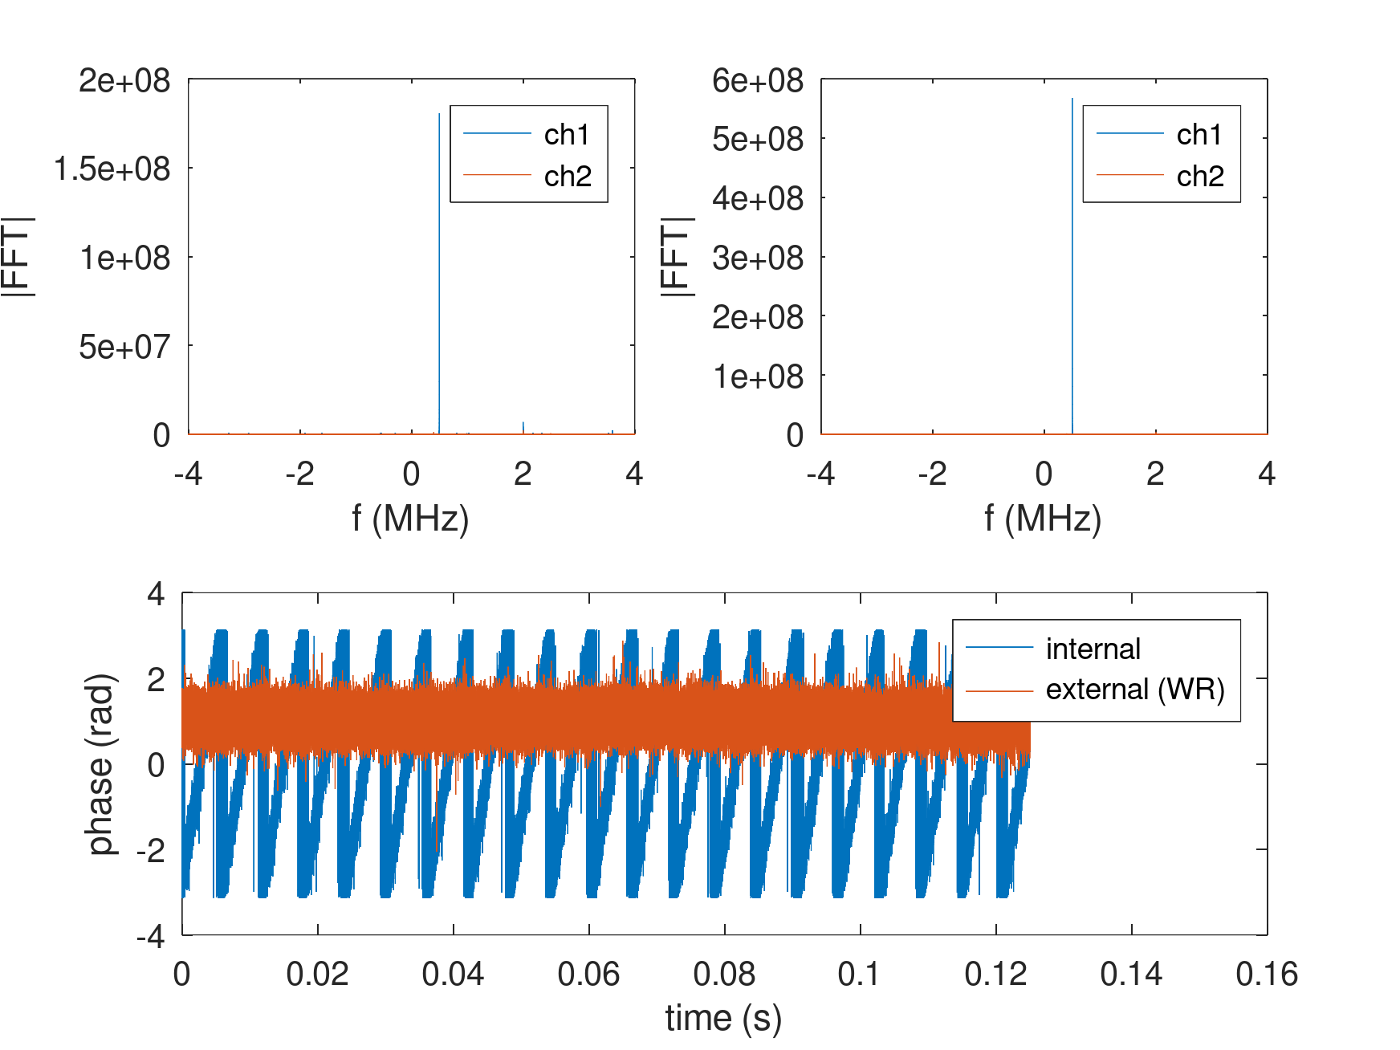
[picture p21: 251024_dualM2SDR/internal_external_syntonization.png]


after repeating with ``-sync white-rabbit`` to demonstrate that the Si5351 is locked on the White Rabbit
disciplined 10 MHz output from the FPGA leading to syntonization.

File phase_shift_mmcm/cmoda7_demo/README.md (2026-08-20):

# Phase shift MMCM demo on CMODA7

This directory contains a demonstration of fine frequency tuning using phase-shifted MMCMs with two phase-noise reductions techniques: sigmadelta noise-shaping and step-size linearization.

## Build and Flash the gateware

To build the gateware you need LiteX+Migen and Vivado configured in the environement, then:
```
./digilent_cmod_a7.py --build
```
or
```
./digilent_cmod_a7.py --build --calib-file normalized_step_sizes.txt
```

And then flash with:
```
openFPGALoader -b cmoda7_35t -f --freq 30e6 -m build/digilent_cmod_a7/gateware/digilent_cmod_a7.bin
```

## Using the demo

The demo gateware needs an input reference clock at 100 MHz on pin `j2:21`, and will output the tuned clock on pin `j2:11` at 62.5 MHz + programmable offset.
The runtime configuration is done via the serial port of the embeded riscv by writing to configuration registers with the commands `mem_write <addr> <val>` and `mem_read <addr>`.

### Configuration registers

To know the addresses of these registers you should fetch them after build with:
```
$ cat build/digilent_cmod_a7/csr.csv | grep dco
csr_register,main_dco_rate,0xf0002000,1,rw
csr_register,main_dco_csr,0xf0002004,1,rw
csr_register,main_dco_stat,0xf0002008,1,ro
```

- `main_dco_rate` is the 24 bits **signed** frequency tuning word, the frequency control is linear with a granularity of 100e6/12/2^24/56/16 ~= 2.2 mHz.

- `main_dco_csr` is a bitfield controling the logic:
    - `main_dco_csr[0]` : RESET, resets all the control logic (except the values of the linearization LUT) and the MMCM's phase position to their deterministic initial state.
    - `main_dco_csr[1]` : SIGMADELTA\_EN, enables the sigmadelta noise-shaping.
    - `main_dco_csr[2]` : LINEARIZATION\_EN, enables the step-size linearization.
    - `main_dco_csr[3]` : START\_CALIB, starts the auto-calibration procedure after a boot or reset, then starts the phase-shift operation, WARNING : it has no effect once the DCO is running, to re-do a calibration you must first RESET.
    - `main_dco_csr[4]` : START\_NO\_CALIB, starts the phase-shift operation immediatly bypassing auto-calibration, this allow to use the manual calibration file specified at synthesis, WARNING : it has no effect once the DCO is running.

- `main_dco_stat` is a bitfield containing information about the DCO current state:
    - `main_dco_stat[0]` : CALIB\_DONE, asserted once the auto-calibration procedure is complete.
    - `main_dco_stat[1]` : DOING\_CALIB, asserted while the auto-calibration procedure is running.
    - `main_dco_stat[16:32]` : DMTD\_TAG, the latest DMTD phase-tag of the tuned clock measured by the embeded DMTD (big-endian)

### Auto-Calibration

1) Reset the logic :
```
litex> mem_write 0xf0002004 1
```

2) Launch the auto-calibration procedure :
```
litex> mem_write 0xf0002004 8
```

3) Wait until `main_dco_stat[0]` is asserted, this should take about 5 minutes. And then it's done.

### Manual Calibration

To create a calibration file you need to measure the phase steps with an external phase-meter such as the 
<a href="https://www.miles.io/PhaseStation_53100A_user_manual.pdf">phase station</a>.

1) Reset the logic, set a null command word (no frequency offset = no phase shifts) and start the DCO without calibration nor sigmadelta :
```
litex> mem_write 0xf0002004 1
litex> mem_write 0xf0002000 0
litex> mem_write 0xf0002004 16
```

2) Start the acquistion on the phase station with a maximum of phase points per seconds (1000 on the phase station) and wait a few seconds get the base phase

3) Set a very small frequency offset so the phase steps are clearly visible on the phase station.
```
litex> mem_write 0xf0002000 5
```

4) Wait at least until the total phase shift reachs 2 ns in order to get an observation of each 112 phase steps, longer acquisitions allow to get more observations per step and to reject some of the low frequency drift.

5) <a href="analyze_tim.m">Process the acquisition</a> to extract the 112 sizes of phase steps and normalize them so that their mean value is 1 (the sum of the normalized steps has to be 112), and save them in a text file separated by newlines, spaces or tabs.

Once you have created this calibration file, you can use it as the default calibration for the next synthesis by passing it via the `--calib-file` argument :
```
./digilent_cmod_a7.py --build --calib-file normalized_step_sizes.txt
```

## Correction application

For using the features, mask 16 (enable) with 4 (phase linearization) and  2 (sigma-delta correction):

Calibrated phase jump correction 
```
mem_write 0xf0002004 20
```
Sigma-Delta
```
mem_write 0xf0002004 18
```
Linearization and Sigma-Delta
```
mem_write 0xf0002004 22
```

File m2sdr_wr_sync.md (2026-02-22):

# Clocking the AD9361 from White Rabbit

This step allow to syntonize multiples M2SDR together using White Rabbit. Note that the SDR will not be syntonized to the White Rabbit clock because the AD9361's fractional PLL cannot synthesize some frequencies exactly, however multiple AD9361 clocked from the same source (White Rabbit clock) with the same configuration will be syntonized together.

## configuration

On the M2SDR, the AD9361 is clocked from an Si5351 which exists in three versions A, B and C. Only version C supports an external CMOS clock input.

The Si5351C `CLK_IN` pin is connected to pin `W22` of the FPGA named `si5351/ssen_clkin` in LiteX. Outputing a White Rabbit clock on this pin and configuring the Si5351 registers to use the `CLK_IN` as reference (registers <a href="https://www.skyworksinc.com/-/media/Skyworks/SL/documents/public/application-notes/AN619.pdf">CLKi_SRC in registers 16+i and Fanout Enable in register 187</a>) will result in the AD9361 syntonization.

This can be done with :

```
./m2sdr_rf -sync white-rabbit [other arguments for the desired rf config]
```

example :
```
./m2sdr_rf -sync white-rabbit -rx_freq 70000000 -rx_gain 20 -samplerate 10000000
```

## Syntonization verification

To check the syntonisation, the most straightforward way is to split a sinusoidal signal to two M2SDRs RX1 ports and record it with `m2sdr_record`.
Then the ratio of the IQ of one file by the other should be constant.

Example with a 70.5 MHz sine wave,

```bash
./m2sdr_rf -sync white-rabbit -rx_freq 70000000 -rx_gain 20 -samplerate 10000000 -c 0 # configure m2sdr0
./m2sdr_rf -sync white-rabbit -rx_freq 70000000 -rx_gain 20 -samplerate 10000000 -c 1 # configure m2sdr1

./m2sdr_record -c 0 /tmp/a.bin 10000000 & ./m2sdr_record -c 1 /tmp/b.bin 10000000 # record the sin wave with both m2sdr
```

Then analyze the phase rotation :
```py
import numpy as np
from matplotlib import pyplot as plt
a = np.fromfile('/tmp/a.bin', dtype='int16')
b = np.fromfile('/tmp/b.bin', dtype='int16')
a = a[::4] + 1j * a[1::4] # the IQ sine wave recorded by m2sdr0
b = b[::4] + 1j * b[1::4] # the IQ sine wave recorded by m2sdr1
plt.plot(np.angle(a / b)) # plot the phase difference, expecting a constant
plt.show()
```

When the SDRs are syntonized, their phase difference is a constant, as illustrated in the plot below:

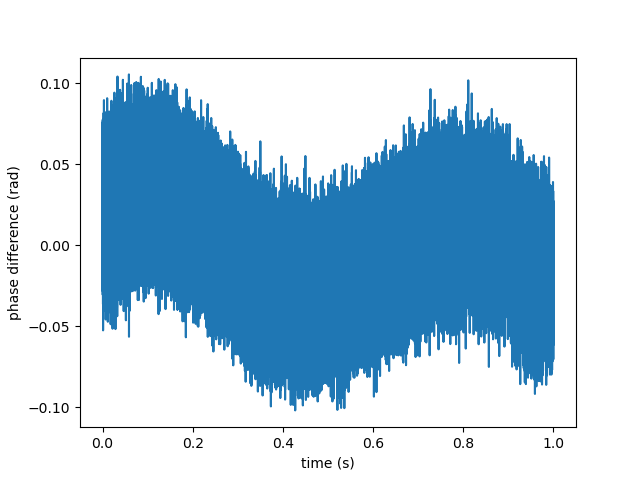
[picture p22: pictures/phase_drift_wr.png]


When they are not, the phase drifts over time :

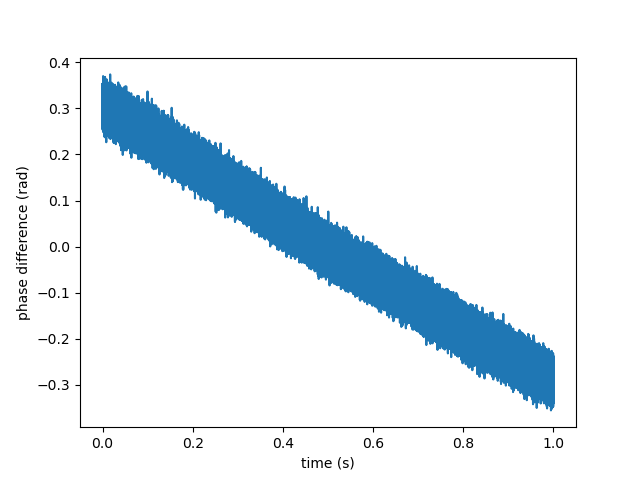
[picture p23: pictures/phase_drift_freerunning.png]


# DMA synchronisation on PPS

This step allows to synchronize the data stream on the PPS, effectively discarding all samples acquiered before the PPS rising edge.

WARNING: this needs White Rabbit to be locked (``phase tracking``). Indeed, White Rabbit will only output a PPS when locked to the master. If White Rabbit is not locked, no PPS will be emitted and the synchronization mechanism will wait for it indefinitely.

## DMA sync configuration

To use the DMA synchronisation, use the option `-dma-sync` on `m2sdr_rf` :

```
./m2sdr_rf -sync white-rabbit -rx_freq 70000000 -rx_gain 20 -samplerate 10000000 -c 1 -dma-sync
```

Then the next time `m2sdr_record` is called, the aquisition will start on the next PPS.

## DMA sync verification

To check the synchronization of the M2SDR, we record a pseudo-random sequence (PRN) starting on the PPS multiple times, and look at the cross correlation.
In our experiment, the PRN is generated with a CMOD-A7 board implementing <a href="https://github.com/oscimp/amaranth_twstft/">amaranth_twstft</a>.

The PRN is repeated 4 times per second, hence the 7 spikes on the cross correlation over one second:
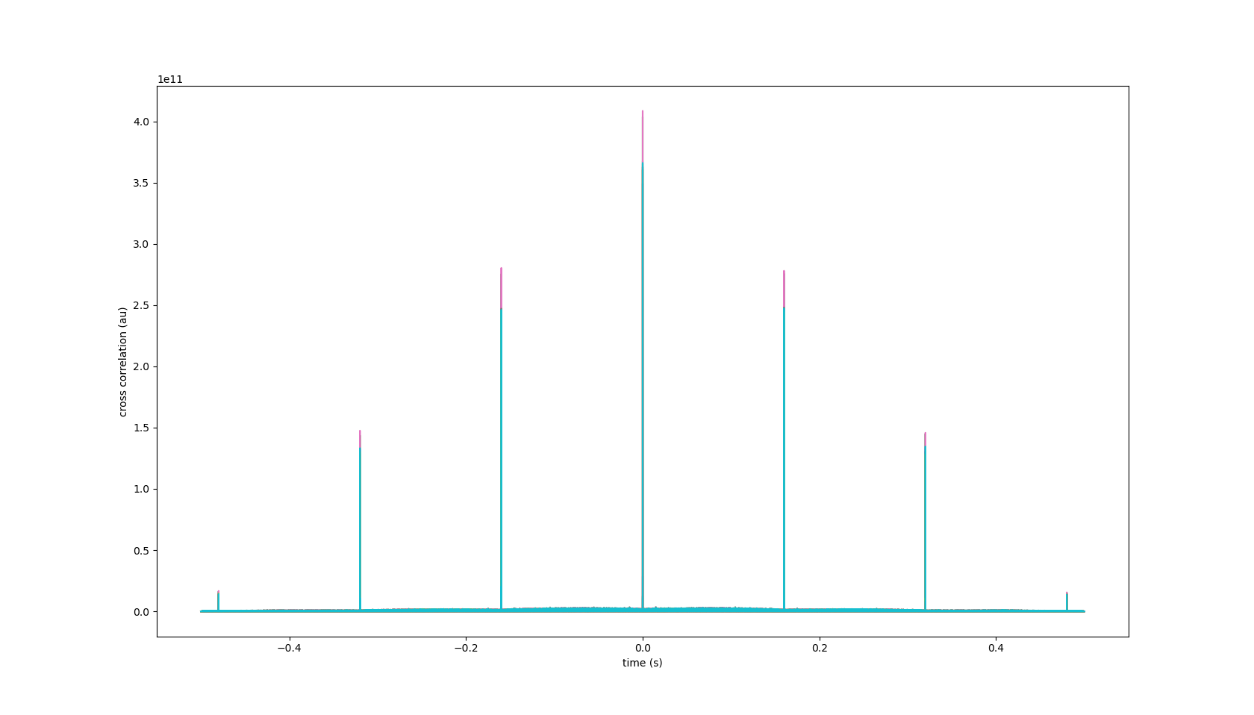
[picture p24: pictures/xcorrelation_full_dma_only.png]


A zoom on the central spike shows that all maximums are in a window of 100 ns, which matches the sampling period, showing that the DMA can synchronize streams up to a sampling period.

To achieve better synchronicity we will need to synchronize the ADC sampling clocks, which is detailed in the next section.
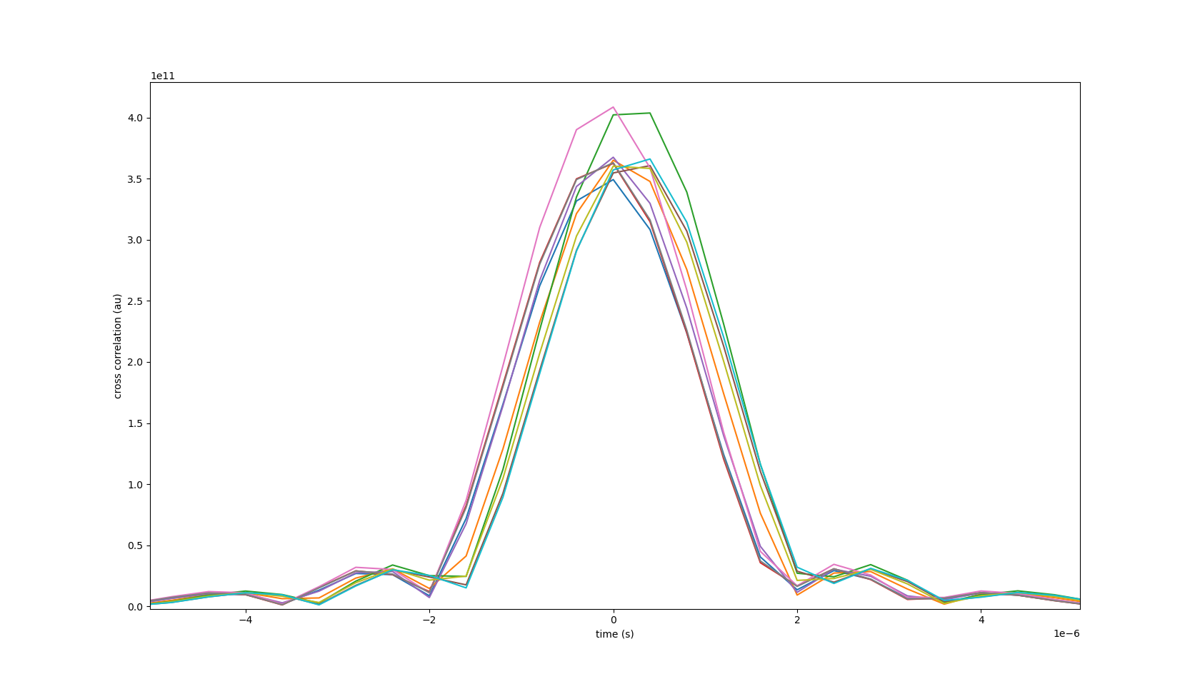
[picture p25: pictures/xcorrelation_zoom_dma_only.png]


# ADC synchronisation

This step allows to synchronize the full datapath in the AD9361 to the White-Rabbit PPS and clock, including ADC clocking, digital filters and data stream clocks.

The RF clocks for the RX and TX mixers cannot be synchronized, they are syntonized on White Rabbit clock but the starting IQ phase is undeterministic (<a href="https://ez.analog.com/cfs-file/__key/telligent-evolution-components-attachments/00-441-00-00-00-07-91-97/AD9361_5F00_Reference_5F00_Manual_5F00_UG_2D00_570.pdf">UG-570</a> p. 87).

## Hardware modification for SYNC\_IN pin

To synchronize its datapath, the AD9361 needs a pulse on its `SYNC_IN` pin. The reference manual states that if two AD9361 are referenced to the same clock with the same configuration, and the `SYNC_IN` pulses are simultaneous, then both datapaths will opperate synchronously.

This pin is not connected to the FPGA on the M2SDR, but can be connected to the SYNDEBUG UFL port, which is controlled by the FPGA.
The `SYNC_IN` signal is accessible under the board near `TP5`, on the left pad of the circled resistor:

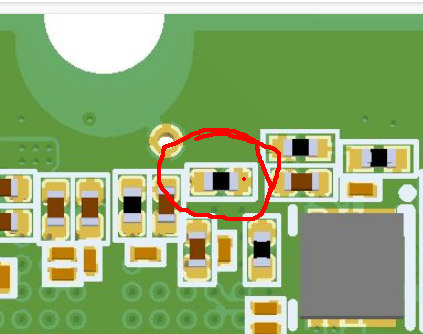
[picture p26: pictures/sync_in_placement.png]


To make the connection sturdy enough we advise to pass an enamel wire through the hole at TP5:

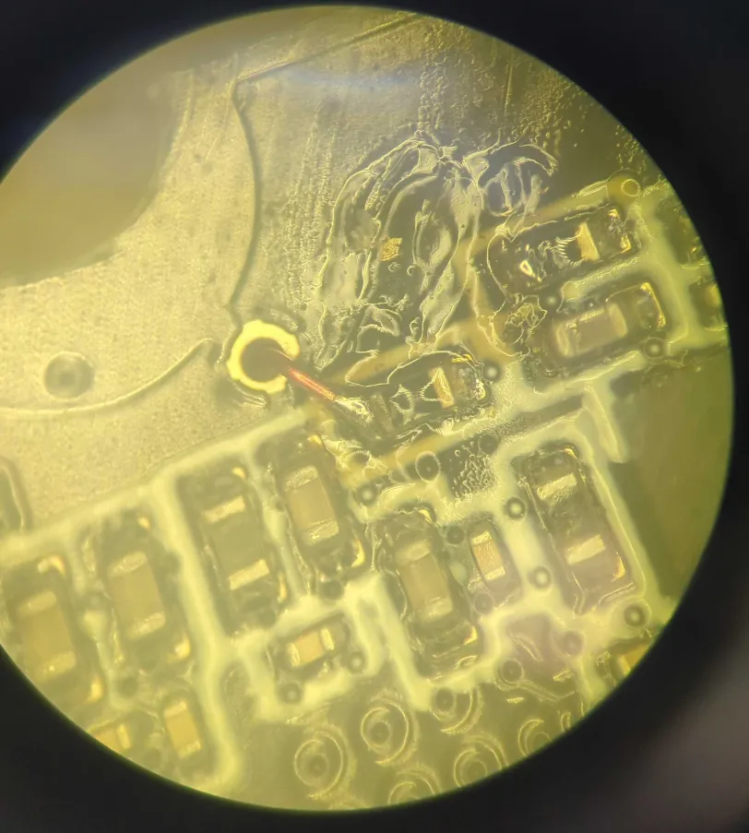
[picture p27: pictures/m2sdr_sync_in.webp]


On the other side, the wire can be soldered to the side of the UFL port, so as not to condemn it for other purposes.

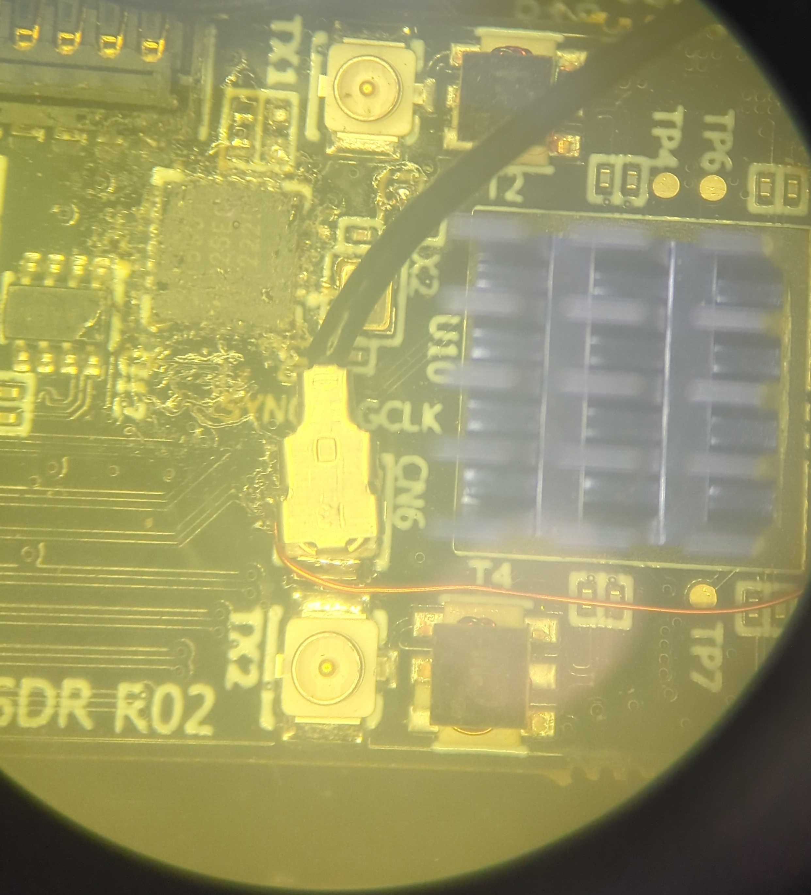
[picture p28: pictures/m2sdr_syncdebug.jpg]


## Si5351C passthrough

To achive synchronisation, the AD9361 of both M2SDR needs to be referenced to the same clock. We assume that the White Rabbit 62.5 MHz clock is the same on all locked M2SDRs.

With the basic syntonization, the White Rabbit 62.5 MHz clock is converted to 10 MHz by a PLL in the FPGA, which in turn is converted to 38.4 MHz by the Si5351C, which then clocks the AD9361.

These PLLs are not deterministic across multiple locks, and result in an unknown phase relationship between the refclks of two AD9361 syntonized on White Rabbit.

To avoid this undeterminism, we use the Si5351 in passthrough mode to clock the AD9361 with the 62.5 MHz from White Rabbit. This frequency is not optimal for the AD9361 to work with, but it is in the operating range.

The 62.5 MHz clock must also be inverted in the Si5351, in order to meet the timming constraints between the clock and the sync pulse (UG-570 p. 88).

## Synchronisation and verification

Once the hardware modification is done, using the ADC synchronisation requires synthesizing the gateware with `--with-white-rabbit --with-adc-sync` options, and use the `-adc-sync` option on `m2sdr_rf`.

Example compilation command:
```
./litex_m2sdr.py --variant=baseboard --with-white-rabbit --with-pcie --build --wr-sfp=0 --wr-dac-bits=24 --with-adc-sync
```

Example m2sdr configuration:
```
./m2sdr_rf -sync white-rabbit -rx_freq 70000000 -rx_gain 20 -samplerate 10000000 -c 1 -dma-sync -adc-sync
```

To test the synchronization, we use the same setup as with the DMA synchronization, and get better results :
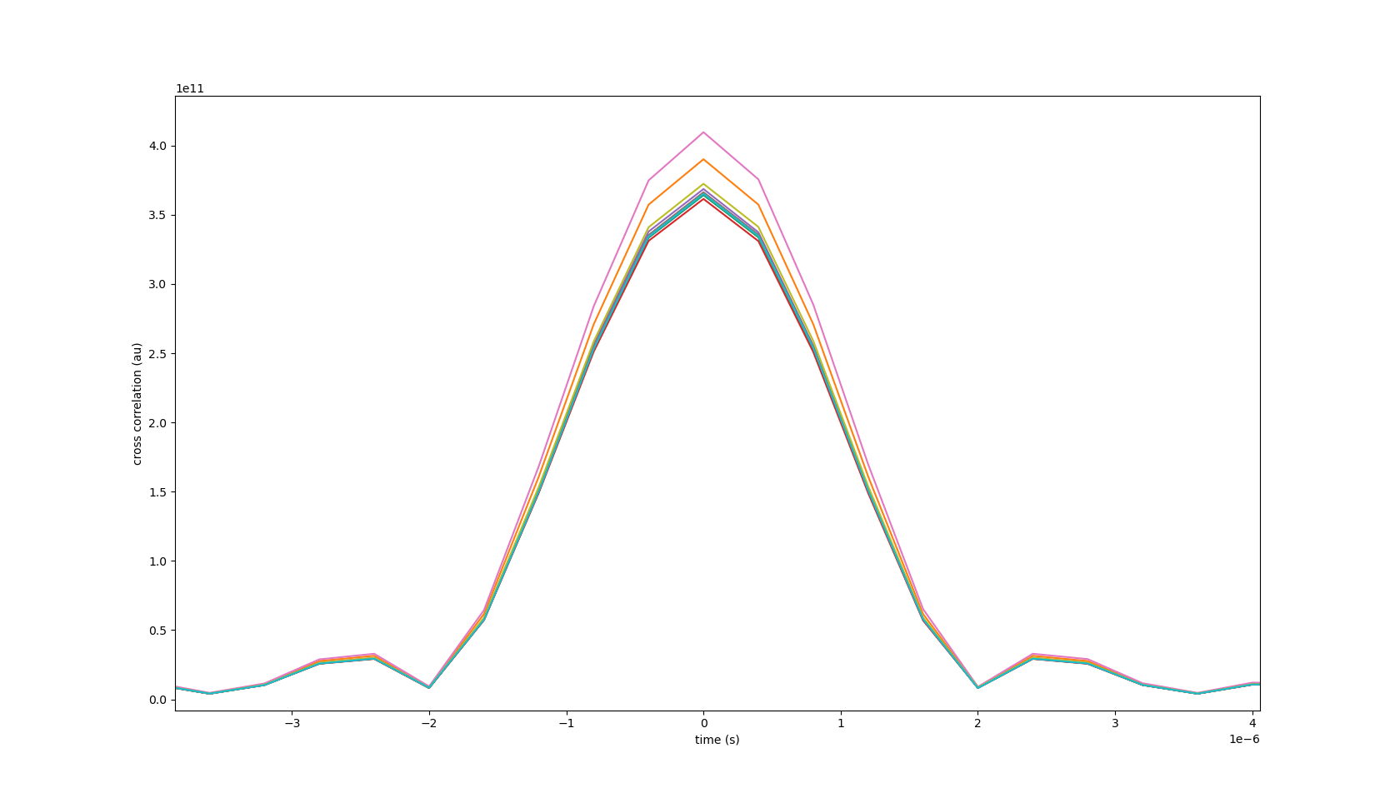
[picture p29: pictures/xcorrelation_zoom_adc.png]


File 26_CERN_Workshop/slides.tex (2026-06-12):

\documentclass[compress,10pt,aspectratio=169]{beamer}
%\setbeamertemplate{background canvas}[bottom=white,top=structure.fg!25]
%\usetheme{Hannover}
%\setbeamertemplate{headline}{}
%\setbeamertemplate{footline}{}
\setbeamersize{text margin left=0.1cm}
\usepackage{appendixnumberbeamer}
\usepackage{hyperref,listings,picinpar,mathtools} % ,enumitem}
\usepackage{color}
\settowidth{\leftmargini}{\usebeamertemplate{itemize item}}
\addtolength{\leftmargini}{\labelsep}
\usepackage{fancyvrb}
%\usepackage{xcolor}
\beamertemplatenavigationsymbolsempty

\definecolor{grey}{rgb}{0.95,0.95,0.95}
\definecolor{red}{rgb}{1.0,0.0,0.0}
\definecolor{green}{rgb}{0.0,0.6,0.0}
\definecolor{blue}{rgb}{0.0,0.0,1.0}
\lstloadlanguages{bash,Java,C,C++,csh,make,sh}%%[Visual]Basic,xml}
\lstset{frame=none,basicstyle=\tiny,breaklines,tabsize=2,captionpos=b,prebreak={\hbox{$\rightarrow$}},postbreak={\hbox{$\hookrightarrow$}},showstringspaces=false,backgroundcolor=\color{grey}\bfseries,keywordstyle=\color{blue},commentstyle=\color{green}\textit,stringstyle=\color{red}\ttfamily,abovecaptionskip=2pt,aboveskip=0pt,belowskip=0pt,belowcaptionskip=0pt}
%\lstset{moredelim=[is][\color{red}]{_+_}{_+_}}

\beamertemplatefootpagenumber
% \setbeamertemplate{footline}[page number]{}
%\setbeamertemplate{page number in head/foot}{}

\setbeamertemplate{footline}[text line]{\hspace*{15.6cm}\insertpagenumber}
\setbeamertemplate{navigation symbols}{}

\usepackage{graphicx,verbatim,multicol,amsmath,bm}
\graphicspath{{./figures/}{../pictures/}}

\lstdefinelanguage{JavaScript}{
  keywords={typeof, new, true, false, catch, function, return, null, catch, switch, var, if, in, while, do, else, case, break},
  keywordstyle=\color{blue}\bfseries,
  ndkeywords={class, export, boolean, throw, implements, import, this},
  ndkeywordstyle=\color{darkgray}\bfseries,
  identifierstyle=\color{black},
  sensitive=false,
  comment=[l]{//},
  morecomment=[s]{/*}{*/},
  commentstyle=\color{purple}\ttfamily,
  stringstyle=\color{red}\ttfamily,
  morestring=[b]',
  morestring=[b]"
}

\lstset{
   language=JavaScript,
   backgroundcolor=\color{lightgray},
   extendedchars=true,
   basicstyle=\footnotesize\ttfamily,
   showstringspaces=false,
   showspaces=false,
   tabsize=2,
   breaklines=true,
   showtabs=false,
   captionpos=b
}

\title{Synchronizing SDR and other clocks on White Rabbit}
\author{\'Emilien Decoux, Jean-Michel Friedt\\ \ \\ 
FEMTO-ST Time \& Frequency department, Besan\c con, France \\ \ 
\\ \ \\ emilien.decoux@edu.univ-fcomte.fr, jmfriedt@femto-st.fr \ \\ \ \\
%project archive at \url{https://github.com/oscimp/wr_acorn}\\
%\vspace{-1.27cm}
\parbox{1.0\linewidth}{\hfill
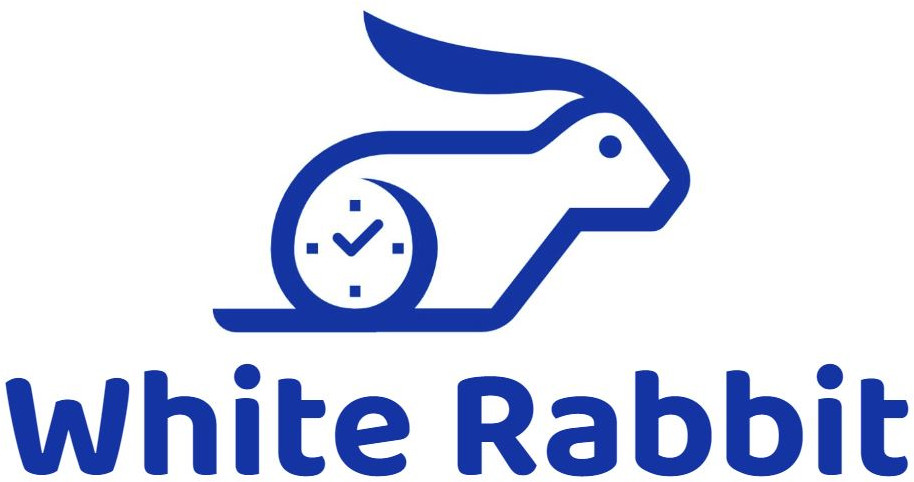
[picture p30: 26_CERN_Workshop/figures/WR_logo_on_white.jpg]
}\vspace{-1cm}  
}

\begin{document}
\maketitle

\begin{frame}[fragile]\frametitle{Outline}

\vspace{-.34cm}
\begin{minipage}[t]{\linewidth}
\begin{minipage}{.59\linewidth}
\vspace{.41cm}
\begin{enumerate}
\item White Rabbit for controlling Software Defined Radio emitters and receivers
\item Syntonisation (openloop)
\item PLL inderminism $\rightarrow$ closed loop synchronization
\item Performance limitation assessment: phase detector noise
\item Aliasing\footnote{C. Calosso, TUT-10: Aliasing in Time and Frequency, IEEE Int. 
Freq. Control Symposium (IFCS, 2026)}
 in {\bf Digital} Dual Mixer Time Difference (DDMTD) and impact of local oscillator phase noise
\end{enumerate}
\vspace{1cm}
\end{minipage}
\begin{minipage}{.42\linewidth}


{\footnotesize Enjoy Digital LiteX M2 SDR at\\
\url{https://enjoy-digital-shop.myshopify.com/products/litex-m2-sdr-si5351b}
and \\\url{https://github.com/enjoy-digital/litex_m2sdr} (firmware+gateware+WR support)\par}
\end{minipage}
\end{minipage}
\end{frame}

\begin{frame}[fragile]\frametitle{Syntonising RF SOCs on White Rabbit}

\begin{itemize}
	\item White Rabbit provides timing for systems of interest, generally by feeding them clocks derived from the main WR clock.
	\item Assumes that no frequency approximation is done in the system of interest (wrong in the AD9361 RFSoC case),
	\item Cannot grant phase synchronisation because of PLL indeterminism.
\end{itemize}


	\begin{center}
		Default M2SDR clock path (open loop)
	\end{center}

\end{frame}

\begin{frame}[fragile]\frametitle{PLL indeterminism}


\begin{minipage}[t]{\linewidth}
\begin{minipage}{.62\linewidth}
{\footnotesize
\begin{itemize}
	\item PLL multiplying by 1.5, division by 2 yields 2 possible phase positions.
	\item Sampling these 2 possible signals at the same time would give 2 patterns: \texttt{10} or \texttt{01}
	\item A PLL with divisor N gives N patterns each N bits long. 
        \item With a LUT we know what position we are in and we can then correct it\footnote{\url{https://wiki.confluence.nikhef.nl/wiki/spaces/WRNIK/pages/934182916/Lock+Sweep}}\footnote{
K. Asteriou, P. Jansweijer, {\em LockSweep (on BabyWR) status and progress}, 14th White Rabbit
Workshop (2025) at \url{https://indico.cern.ch/event/1524513/contributions/6556312/}}: Nikhef's {\bf locksweep}
	\item By simulating the sampling of the patterns, we can {\bf automatically generate the LUT for given frequencies}
\end{itemize}}
\end{minipage}
\begin{minipage}{.47\linewidth}
\hspace*{-0.1cm}

\vspace{-.4cm}
{\footnotesize \hspace*{.9cm}A PLL dividing by 5 yields 5 possibilities}
\end{minipage}
\end{minipage}
\end{frame}

\begin{frame}[fragile]\frametitle{Auxiliary locksweep}

\begin{itemize}
	\item Auxiliary soft PLLs cost an extra VCO, and offer fine phase control over a 62.5 MHz feedback clock.
	\item This solves the frequency approximation issue,
	\item Using the phase sampler and fine phase control, we can correct the PLL indeterminism.
\end{itemize}


	\begin{center}
		Locksweep M2SDR clock path (closed loop)
	\end{center}
\end{frame}

\begin{frame}[fragile]\frametitle{Auxiliary locksweep}

\begin{minipage}[t]{\linewidth}
\begin{minipage}{.49\linewidth}



\end{minipage}
\begin{minipage}{.49\linewidth}
\begin{itemize}
\item Microchip 53100A Phase Noise Analyzer repeated measurements with White Rabbit reset between each measurement
\item Reference = WRS 10~MHz output~; measurement = M2SDR WR disciplined (locksweep) 10~MHz output
\item The phase aligns on the same value after each reset
\end{itemize}
\end{minipage}
\end{minipage}
\end{frame}

\begin{frame}[fragile]\frametitle{Sidenote: automating measurements using the 53100A Phase Station
\footnote{see \url{https://github.com/oscimp/wr_acorn/tree/main/phase_station_mqtt}}}

\begin{minipage}[t]{\linewidth}
\begin{minipage}{.47\linewidth}
{\footnotesize
\begin{itemize}
\item the 53100A control software runs on a MS-Windows computer
\item the 53100A control software includes a Javascript interpreter
\item synchronizing the GNU/Linux White Rabbit configuration and analysis
script with 53100A control software through an MQTT broker (server)
\item publish-subscribe (PUB-SUB) ping-pong exchange for synchronizing 53100A data
acquisition and White Rabbit reconfiguration
\end{itemize}
}



\end{minipage}
\begin{minipage}{.59\linewidth}

\begin{lstlisting}[language=JavaScript,basicstyle=\scriptsize\ttfamily]
const mqtt_broker="192.168.1.170";   // mqtt server IP
var acq_num = 0; // global var to remember between acq
function EventRunScript()  // launched at startup
{prep_acq(); start_acq(); acq_num = 0; }

function prep_acq()
{ AcqClearParams();
  AcqSetParam("Measure Stability", "True");
  AcqSetParam("Measure PM Noise",  "True");
  [...]
}

function start_acq()
{FileExecuteWait("c:\\Program Files\\Mosquitto\\mosquitto_sub.exe", " -h "+mqtt_broker+" -t locksweeping -C 1")) 
 AcqStartAcquisition("Microchip 53100A ...",true);
}

function EventAcqDone() // called after each acq.
{FileSave("save_" + acq_num + ".tim");
 ++acq_num;
 FileExecute("c:\\Program Files\\Mosquitto\\mosquitto_pub.exe", " -h "+mqtt_broker+" -t locksweep_now -m acq_done"))
 FileCloseAllPlots();
 prep_acq();             // check Phase Station config
 start_acq();                   // restart acquisition
 if (acq_num >= 10000) { ScriptEnd(); }
}
\end{lstlisting}
\end{minipage}
\end{minipage}
\end{frame}

\begin{frame}[fragile]\frametitle{SDR synchronization demonstration}

\begin{minipage}[t]{\linewidth}
\begin{minipage}{.49\linewidth}
{\footnotesize
\begin{itemize}
\item Feed the AD9361 input with a BPSK modulated carrier carrying a pseudo-random sequence (2.5 Mchips/s)\footnote{\url{https://github.com/oscimp/amaranth_twstft/}}
\item Cross-correlation of the IQ stream to identify delay with a resolution improvement
over the sampling rate equal to the SNR
\item Repeat after restarting WR to assess proper phase alignement of the recorded IQ stream
(ADC clock synchronization)
\item However, the receiver local oscillators remain free running: random RF phase between
SDR receivers despite fine phase alignement of the ADC samples (problem for electronic beam/null
stearing).
\end{itemize}
}

\vspace{0.2cm}

\end{minipage}
\begin{minipage}{.54\linewidth}
\vspace{-.71cm}
\hspace*{1cm}

{\footnotesize No locksweep: acquisition begins at PPS $\Rightarrow$ correlation peaks are in the same sampling period
(50~ns @ 20~MS/s).\par}

\hspace*{1cm}

{\footnotesize With locksweep: ADC clock is synchronised on White Rabbit $\Rightarrow$ correlation peaks are synchronized ($\sigma=1$~ns, limited by AD9361).\par}
\end{minipage}
\end{minipage}

\end{frame}

\begin{frame}[fragile]\frametitle{What is the critical element of White Rabbit?}
\begin{minipage}{.49\linewidth}
{\footnotesize
\begin{itemize}
	\item White Rabbit can synchronize off-the-shelf SDRs,
	\item at the cost of poor phase noise, even at low frequencies (uncleanable).
	\item Where does the phase noise come from?
	\item Where does it irremediably affect White Rabbit?
\end{itemize}}


\end{minipage}
\begin{minipage}{.49\linewidth}

\only<1>{\hspace*{1cm}}
\only<2>{{\footnotesize C. Calosso, TUT-10: Aliasing in Time and Frequency, IEEE Int. 
Freq. Control Symposium (IFCS, 2026):\par}

\hspace*{1cm}}

{\footnotesize
\begin{itemize}
	\item High frequency phase noise can be cleaned by external oscillators (SI5351's job on the m2sdr)
	\item Noisy clocks are processed by the DDMTD into WR's control loop.
\end{itemize}}
\end{minipage}
\end{frame}

\begin{frame}[fragile]\frametitle{DDMTD aliasing}

\begin{minipage}{.49\linewidth}
\begin{centering}

\end{centering}

{%\footnotesize
\begin{itemize}
	\item DDMTD sub-sample the clock at $2^{15}$x Nyquist frequency
	\item this alias the high frequency of the clock to a low frequency, which's phase can be measured by a timer.
	\item The broadband digital gates also alias phase noise and spurs into the DDMTD bandwith (1.9~kHz)\footnote{Rizzi, Mattia \& Lipinski, Maciej \& Wlostowski, Tomasz \& Serrano, Javier \& Daniluk, Grzegorz \& Ferrari, P. \& Rinaldi, Stefano. (2016). White rabbit clock characteristics. 1-6. 10.1109/ISPCS.2016.7579514.}
\end{itemize}}
\end{minipage}
\begin{minipage}{.49\linewidth}


	{\footnotesize A spur at any frequency offset is folded into a low frequency spur, much harder to filter out.\par}


\end{minipage}

\end{frame}

\begin{frame}[fragile]\frametitle{DDMTD aliasing}

\begin{minipage}{.49\linewidth}

\begin{centering}

\end{centering}

{%\footnotesize
\begin{itemize}
	\item The same amount of noise is aliased into the DDMTD bandwidth
	\item Increasing the bandwidth proportionaly lowers the noise floor
\end{itemize}}

$\Rightarrow$ DDMTD integrates all the oscillator noise in the soft PLL phase detection, 
degrading low frequency phase noise.
\end{minipage}
\begin{minipage}{.49\linewidth}
DDMTD output phase noise for different beat frequencies:


\end{minipage}
\end{frame}

\begin{frame}[fragile]\frametitle{Noise induced by MMCM phase shifts aliased in the DDMTD}
\begin{minipage}{.49\linewidth}

\end{minipage}
\begin{minipage}{.49\linewidth}
\begin{itemize}
	\item MMCM phase shifts produce phase noise spurs
	\item These spurs offsets from 62.5~MHz are proportionnal to the offset frequency generated by the phase shifts
	\item Since their positions are predictable, could they be selectively filtered ?
	\item Else, can we use less phase shifting MMCMs ?
\end{itemize}
\end{minipage}

Spectrum of the DDMTD output in the M2SDR depending on the MMCM generated frequency offset.

\end{frame}

\begin{frame}[fragile]\frametitle{Low-cost WR without MMCM tuning}

Alternatives to phase-shifted MMCMs in VCO-less White Rabbit:
\begin{itemize}
	\item Chained PLLs for helper
	\item TXPI PPM (picxo) for main tuning
\end{itemize}

\vspace{-0.63cm}\begin{center}

\end{center} % TODO replot

\end{frame}

\begin{frame}[fragile]\frametitle{Conclusion}

\begin{minipage}[t]{\linewidth}
\begin{minipage}{.49\linewidth}
\begin{itemize}
\item Functional implementation of White Rabbit on the Artix7 of the M2SDR controlling the
AD9361
\item Validation of the fine delay tuning by monitoring broadband cross-correlation peak
position with an accuracy $\ll$ than sampling period
\item No hardware modification (1-PPS to Sync\_In of AD9361) thanks to the locksweep using
Aux. PLL to control the phase of the clock to align the sampling clock to the WR clock.
\end{itemize}
\end{minipage}
\begin{minipage}{.49\linewidth}

\end{minipage}
\end{minipage}

\vspace{0.2cm}
\begin{minipage}[t]{\linewidth}
\begin{minipage}{.87\linewidth}
Software repositories
\begin{itemize}
\item \url{https://github.com/oscimp/wr_acorn}
\item M2SDR support at
\url{https://github.com/enjoy-digital/litex_m2sdr}
\item wrpc-sw with locksweep (merge in progress):
\url{https://gitlab.com/Mimil25/wrpc-sw/-/tree/merge_locksweeps}
\end{itemize}
\end{minipage}
\begin{minipage}{.12\linewidth}

\end{minipage}
\end{minipage}
\end{frame}

% bonus slides

\begin{frame}[fragile]\frametitle{DDMTD noise function}

\begin{minipage}[t]{1.041\linewidth}
\begin{minipage}{.49\linewidth}


Aliasing weight as a function of spur frequency
\end{minipage}
\begin{minipage}{.49\linewidth}


Map of aliasing weight as a function of spur frequency and amplitude
\end{minipage}
\end{minipage}
\end{frame}

\end{document}

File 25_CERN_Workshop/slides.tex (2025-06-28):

\documentclass[compress,10pt,aspectratio=169]{beamer}
%\setbeamertemplate{background canvas}[bottom=white,top=structure.fg!25]
%\usetheme{Hannover}
%\setbeamertemplate{headline}{}
%\setbeamertemplate{footline}{}
\setbeamersize{text margin left=0.1cm}
\usepackage{appendixnumberbeamer}
\usepackage{hyperref,listings,picinpar,mathtools} % ,enumitem}
\usepackage{color}
\settowidth{\leftmargini}{\usebeamertemplate{itemize item}}
\addtolength{\leftmargini}{\labelsep}
\usepackage{fancyvrb}
%\usepackage{xcolor}
\beamertemplatenavigationsymbolsempty

\definecolor{grey}{rgb}{0.95,0.95,0.95}
\definecolor{red}{rgb}{1.0,0.0,0.0}
\definecolor{green}{rgb}{0.0,0.6,0.0}
\definecolor{blue}{rgb}{0.0,0.0,1.0}
\lstloadlanguages{bash,Java,C,C++,csh,make,sh}%%[Visual]Basic,xml}
\lstset{frame=none,basicstyle=\tiny,breaklines,tabsize=2,captionpos=b,prebreak={\hbox{$\rightarrow$}},postbreak={\hbox{$\hookrightarrow$}},showstringspaces=false,backgroundcolor=\color{grey}\bfseries,keywordstyle=\color{blue},commentstyle=\color{green}\textit,stringstyle=\color{red}\ttfamily,abovecaptionskip=2pt,aboveskip=0pt,belowskip=0pt,belowcaptionskip=0pt}
%\lstset{moredelim=[is][\color{red}]{_+_}{_+_}}

\beamertemplatefootpagenumber
% \setbeamertemplate{footline}[page number]{}
%\setbeamertemplate{page number in head/foot}{}

\setbeamertemplate{footline}[text line]{\hspace*{15.6cm}\insertpagenumber}
\setbeamertemplate{navigation symbols}{}

\usepackage{graphicx,verbatim,multicol,amsmath,bm}
\graphicspath{{./figures/}{../pictures/}}

\title{Yet Another White Rabbit running on a low-cost, generic FPGA board}
\author{\'Emilien Decoux, Jean-Michel Friedt\\ \ \\ 
FEMTO-ST Time \& Frequency department, Besan\c con, France \\ \ 
\\ \ \\ emilien.decoux@edu.univ-fcomte.fr, jmfriedt@femto-st.fr \ \\ \ \\
project archive at \url{https://github.com/oscimp/wr_acorn}\\
%\vspace{-1.27cm}
\parbox{1.0\linewidth}{\hfill
}\vspace{-1cm}  
}

\begin{document}
\maketitle

\begin{frame}[fragile]\frametitle{Context and outline}

\vspace{0.1cm}
{\footnotesize
\begin{itemize}
\item White Rabbit (WR) supported boards require two {\bf dedicated} oscillators for generating
the digital phase detector (DMTD)
\item WR as feature of generic boards (RF signal acquisition and synthesis, {\bf Software 
Defined Radio} -- SDR) requires getting rid of this requirement
\end{itemize}
}
\begin{minipage}[t]{\linewidth}
\begin{minipage}{.55\linewidth}    
{\footnotesize
\begin{itemize}
\item $\Rightarrow$ {\bf timing library compatible with any existing FPGA based acquisition/synthesis
board} (at the expense of performance?)
\item Use of clocking circuits internal to the FPGA for generating WR clocks
\footnote{See ``More challenging that I can imagine'' on slide 8 of D. Charlet {\em \& al}, {\em Performance evaluation of a versatile and low-jitter
White Rabbit board} at 13th White Rabbit Workshop, CERN (Mar. 2024)}
\item Demonstration on Enjoy Digital's Acorn CLE215+ board...
\item ... Xilinx Artix-7 A100T FPGA / 1 Gb DDR $\Rightarrow$ start from Nikhef's  CLBv3 design and Missing Link Electronics' 2024 contribution\footnotemark
\footnotemark
\end{itemize}
}
\end{minipage}
\begin{minipage}{.49\linewidth}

\end{minipage}
\end{minipage}
\footnotetext{\url{https://enjoy-digital-shop.myshopify.com/products/litex-acorn-baseboard-mini-sqrl-acorn-cle215}}
\footnotetext{13th White Rabbit Workshop (CERN), \url{https://www.missinglinkelectronics.com/wp-content/uploads/2024/03/MLE-Light-Rabbit-Presentation-at-13th-White-Rabbit-Workshop.pdf}}
\end{frame}

\begin{frame}[fragile]
\frametitle{Mixed-Mode Clock Manager (MMCM) phase-shifts for VCXO replacement}
\begin{minipage}{.74\linewidth}
Simulation v.s experimental phase noise spectra



$\rightarrow$ accurate understanding of the MMCM spurious sources
\end{minipage}
\begin{minipage}{.25\linewidth}

\end{minipage}
\end{frame}

\begin{frame}[fragile]\frametitle{VCO-less DMTD implementation and phase detection characterization}

What element of the control loop is limiting overall performance?

\vspace{0.3cm}
\begin{minipage}[t]{1.06\linewidth}
\begin{minipage}{.49\linewidth}

\only<1>{\input{figures/principle.pspdftex}}
\only<2>{\vspace{-0.2cm}\begin{minipage}[t]{\linewidth}
DDMTD characterization setup
\vspace{0.4cm}


\vspace{0.2cm}
\end{minipage}
}

\begin{itemize}
\item Initial tests of CMOD-A7 Artix-7 generic board
\item PLL frequency $f_{PLL}=62.5$~MHz and beatnote $f_b=3$~kHz $\Rightarrow$ counter $c$ converted
to phase as $$\varphi=2\pi\cdot c\cdot f_b/f_{PLL}$$
\item phase to phase noise density $$S_\varphi=\frac{\sigma^2_\varphi}{f_b}\mbox{ @ }f_b$$
\item phase spectral density using {\tt pwelch} $\nearrow$
\end{itemize}
\end{minipage}
\begin{minipage}{.49\linewidth}
\vspace{0.0cm}
%All control loop steps characterized in the frequency domain (phase noise
%at $f_{Fourier}$ offset from carrier) and time domain (Allan deviation)



\begin{itemize}
\item $f_{PLL}=62.5$~MHz $\Rightarrow$ scale by $N^2=(f_o/f_{PLL})^2=-16$~dB if
$f_o$=10~MHz.
\end{itemize}
\end{minipage}
\end{minipage}
\end{frame}

\begin{frame}[fragile]\frametitle{Reference clock characteristics}

\begin{minipage}[t]{\linewidth}
\begin{minipage}{.49\linewidth}

\end{minipage}
\begin{minipage}{.54\linewidth}
\input{figures/principle.pspdftex}
\vspace{0.4cm}

  \begin{itemize}
    \item 1 -- 20 Hz: limited by RX clock from GTP
    \item 20 Hz -- 3.8 kHz: limited by DMTD and/or softPLL
    \item 3.8 kHz -- 1 MHz: limited by VCO (MMCM with phase-shifts)
    \item 5 kHz -- 1 MHz: spurious from MMCM with phase-shifts
  \end{itemize}
\end{minipage}
\end{minipage}
\end{frame}

\begin{frame}[fragile]\frametitle{HDL implementation on CLE215+: {\footnotesize\url{https://github.com/oscimp/wr_acorn}}}

  \begin{itemize}
    \item \texttt{board/acorn/} - FPGA-internal HDL
      \begin{itemize}
        \item \texttt{Manifest.py} - hdlmake imports
        \item \texttt{wr\_acorn\_pkg.vhd} - hdl header
        \item \texttt{xwrc\_board\_acorn.vhd} - logic around \texttt{xwrc\_platform\_xilinx} and \texttt{xwrc\_board\_common}
          \begin{itemize}
            \item \texttt{xwrc\_board\_common} expose dac interfaces outputs and clock inputs
            \item traditionnal WR convert \texttt{data+load} to I²C/other dac protocol
            \item VCO-less WR convert \texttt{data+load} to MMCM's phase-shift control
          \end{itemize}
      \end{itemize}
    \item \texttt{top/acorn\_ref\_design/} - FPGA/board interface files

          \texttt{acorn\_wr\_ref\_top.xdc} - set io pins and allow internal clocking of the GTP ports
    \item \texttt{syn/acorn\_ref\_design/} - synthesis related files
          add custom \texttt{bitstream.tcl} to allow internal clocking of the GTP ports
    \item \texttt{platform/Xilinx} - add generic to allow internal clocking of the GTP ports
  \end{itemize}

\end{frame}

\begin{frame}[fragile]\frametitle{LiteX implementation on CLE215+ \& M2SDR:\\
\vspace{-.3cm}{\footnotesize\url{https://github.com/enjoy-digital/litex_wr_nic}}}

\vspace{.3cm}
\begin{minipage}[t]{1.05\linewidth}
\begin{minipage}{.66\linewidth}
{\scriptsize
\begin{Verbatim}[commandchars=\\\{\}]
wrc# pll stat
softpll: mode:3 seq:ready n_ref 1 n_out 1
irqs:123226 alignment_state:0 {\color{green}HL1 ML1} HY=23493 MY=40133 DelCnt=0 setpoint:13037 refcnt:66565 tagcnt:53
softpll: ptracker0: enabled 1 n_avg 512 value 13575
wrc# gui
SPA7 WRPC Monitor wrpc-v5.0-ohwr-9-g5ac04dd5-dirt | Esc/q = exit; r = redraw

TAI Time: 2023-03-03-11:55:43  UTC offset: 37   PLL mode: BC  state: Locked
---+-------------------+-------------------------+---------+---------+-----
 # |        MAC        |       IP (source)       |    RX   |    TX   | VLAN
---+-------------------+-------------------------+---------+---------+-----
 0 | 22:33:44:55:66:77 |                         |     555 |     183 |    0
--- HAL ---|------------- PPSI ------------------------------------------------
 Itf | Frq |  Config   | MAC of peer port  |    PTP/EXT/PDETECT States   | Pro 
-----+-----+-----------+-------------------+-----------------------------+-----
 wr0 | Lck | auto      | 70:b3:d5:91:ea:f0 | SLAVE    /IDLE      /EXT_ON | R-W 
Pro(tocol): R-RawEth, V-VLAN, U-UDP

--------------------------- Synchronization status ----------------------------
Servo state:          White-Rabbit: {\color{green}TRACK_PHASE}

--- Timing parameters ---------------------------------------------------------
meanDelay        :              284.572 ns
delayMS          :              284.572 ns 
delayMM          :             1097.210 ns 
delayAsymmetry   :                0.000 ns
delayCoefficient :   +0.000000000000000000  fpa   0
\end{Verbatim}
}
\end{minipage}
\begin{minipage}{.33\linewidth}


{\footnotesize M2SDR running White-Rabbit PTP core with 1~PPS output\par}
\end{minipage}
\end{minipage}
\end{frame}

\begin{frame}[fragile]\frametitle{Results: Acorn CLE215+}

Tuning software phase locked-loop (PLL) control coefficients

\begin{minipage}[t]{1.06\linewidth}
\begin{minipage}{.49\linewidth}
\only<1>{

Modified Allan deviation: phase flicker noise measured on 1-PPS output
}
\only<2>{

{\footnotesize Low quality 200~MHz MEMS oscillator (Abracon \\ASDMPLV-200.000MHZ): $\sigma_\tau=0.5$~ps @ 62.5~MHz:\\
$10\log_{10}\left(\frac{(2\pi\times 62.5\cdot 10^6\times 0.5\cdot 10^{-12})^2}{10^5}\right)=-124$~dBrad$^2$/Hz\par
\par}
}
\end{minipage}
\begin{minipage}{.49\linewidth}


Phase noise (Rohde \& Schwarz FSWP, 10~MHz output)
\end{minipage}
\end{minipage}

\end{frame}

\begin{frame}[fragile]\frametitle{Results: M2SDR}

\begin{minipage}[t]{1.07\linewidth}
\begin{minipage}{.49\linewidth}


100~MHz TCXO oscillator, measurement on 1-PPS output
\end{minipage}
\begin{minipage}{.49\linewidth}


\hfill Phase noise, 10~MHz output
\end{minipage}
\end{minipage}
\end{frame}

\begin{frame}[fragile]\frametitle{Conclusion \& perspectives}

\vspace{.11cm}
\begin{minipage}[t]{\linewidth}
\begin{minipage}{.55\linewidth}
{\footnotesize
\begin{itemize}
\item Initial steps for becoming familiar at FEMTO-ST with WR architecture and internals on Artix7
\item Functional demonstration, repository at \url{https://github.com/oscimp/wr_acorn}
\item Impact of internal oscillator usage on phase noise and Allan deviation performance
\item In progress: port to M2SDR {\bf with its AD9361 frontend}
\item {\bf Challenge}: can modern FPGA, with flexible clock sources, compete with high stability external (quartz)
oscillators?
\end{itemize}

\vspace{.11cm}
{\bf Acknowledgements:}
\begin{itemize}
    \item Peter Jansweijer (Nikhef) for updating the CLBv3 design, 
    \item Frederik Pfautsch (Missing Link Electronics) for committing the various VCO-less implementations, 
    \item Florent Kermarrec and Gwenhael Goavec-Merou (Enjoy Digital) for providing the
    hardware boards and LiteX implementations
    \item CERN's White Rabbit team (Tomasz Wlostowski, Tristan Gingold \& others) 
    \item Claudio Calosso (INRIM) for fruitful discussions $\nearrow$
    \end{itemize}
}
\end{minipage}
\begin{minipage}{.495\linewidth}


{\footnotesize
Impact of FPGA gate size and phase noise performance during the
2025 IFCS Tutorial on low noise digital electronics
\footnote{C.E. Calosso \& E. Rubiola {\em Phase noise and jitter in digital electronics},
Proc EFTF (2014) 374--376 at \url{https://arxiv.org/pdf/1701.00094}}\par
}
\end{minipage}
\end{minipage}
\end{frame}
\end{document}

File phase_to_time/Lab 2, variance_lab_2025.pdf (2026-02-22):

## Variance measurements – EFTS 2025

Franc¸ois Vernotte

June 21, 2025

## Warning

For this lab session, you will use a Graphical User Interface version of SigmaTheta (see § Resources, page 6) which is still under test. Please be lenient if you encounter any bugs while running this version, and provide feedback to the authors for correction!

## 1 Getting started


Figure 1: Startup screen graphical user interface.

At start, your configuration screen should look like figure 1. In this case, close the window “untitled
- GNU Radio Companion” which will be used in another laboratory session.
If this is not the case, open two file manager windows, one containing the datasets, the other which will be your working folder (“playground” in the figure) and make sure to copy the content of “datasets” to “playground” to always keep a safe copy of the original files. In the parent folder (“variance lab”), there is the PDF file corresponding to this book-
let “variance lab 2025.pdf” that you already have since you are
reading these lines. You can read it
by using the command line :
xpdf ../variance lab 2025.pdf
On the other hand, all the data are in
the folder “dataset”.
You can use “Shift-Alt” to switch between English (“QWERTY”) and French (“AZERTY”) keyboard layouts.

1

EFTS 2025 – Variance Measurements | 2

## 2 Example of Allan variance computation

The Allan variance (AVAR) computation is quite simple:

σ

2
y

(τ ) = 1
2

D
(¯y2 − y¯1)

2

E
, | (1)

where < · > stands for mathematical expectation. In order to prove this assertion, let us compute the Allan variance with a spreadsheet software (gnumeric) on a very small 10 item-file: tuto Allan.ykt.

1. Open a terminal (fourth icon on the menu bar at the bottom of the window manager named “XTerm”)
and go to the playground/ folder (cd ˜/variance_lab/playground).
2. Copy the tuto Allan.ykt file from the dataset/ folder to the playground/ folder:
cp ../dataset/tuto Allan.ykt .
3. First, have a look on this file:
less tuto Allan.ykt exhibits two columns after a header defining the measurement conditions
4. Load it with gnumeric: in the terminal, after quitting less with q, type
gnumeric tuto Allan.ykt &
5. Use the definition of AVAR (1) in gnumeric to compute the estimator for τ = 1, 2, 3 and 5 s.
6. Compare these Allan variance results with the Allan deviation results obtained by the command-line software ADev:
ADev tuto Allan.ykt
Are they compatible?

## 3 About the software SigmaTheta-gui


Figure 2: The SigmaTheta-gui graphical user interface.

In the command line window, type “SigmaTheta-gui” to run the software. You will get a new window like the figure 2. The important features are

- the top banner which displays several commands (e.g. ’New’ for adding a new frame, ’Run’ for computing the deviation, etc.)
- the left window which allows modifying some parameters (e.g the deviation type, the display of asymptote, etc.)
- the main right window showing either a plot of the input data (Preview), a plot of the results (Plot serie) or a numerical table of the results (Table serie).

More details will be given in the following.

## 4 Analysis of the file Cs hour.ykt

- Clock: Cs clock
- Data: frequency deviation samples
- Sampling period: 1 hour
- Number of samples: 100 000

### 4.1 Preliminary observation

Import the file variance lab/datasets/YkGraph Cs hour.ykt and look at the preview.

### 4.2 Frequency stability assessment

1. Check that the Deviation Type is set to ADEV and compute the Allan deviation of this file by clicking on the Run button.
2. Observe the asymptote coefficients which are displayed on the graph if the box Display asymptote is enabled. Be aware that these asymptotes fit the ADev curve and not the AVar curve. . .
3. Translate these coefficients in terms of noise levels of the Power Spectral Density (PSD) thanks to Table 1.
4. Observe the PSD by clicking on the Sy button on the top banner. Is it compatible with the noise levels that you estimated ?

## 5 Analysis of the file HM minute.xtt

- Clock: hydrogen Maser
- Data: time errors
- Sampling period: 1 minute
- Number of samples: 200 000

Click on the New button to get a new frame.

### 5.1 Preliminary observations

1. Import and observe HM minute.xtt.
2. Convert the phase data into frequency data thanks to the X→Y button and observe them.
3. What do you observe?

### 5.2 Frequency stability assessment

1. Plot the Allan deviation of the frequency data.
2. Determine the power law asymptotes.
3. Estimate the coefficients of the power laws.
4. Calculate the corresponding noise levels of the PSD.
5. What is the meaning of the τ

+1 asymptote?

6. Compute the drift level from the corresponding asymptote.

Table 1: Response of the Allan variance, Modified Allan variance and Hadamard variance for the different types of noises and a linear drift. fh represents the high cut-off frequency.

Sy(f) (s) | 2 σ (τ ) y | 2 Modσ (τ ) y | 2 σ H(τ )
−2 h−2f | 2π 2h−2τ 3 | 11π 2h−2τ 20 | π 2h−2τ 3
−1 h−1f | 2 ln(2)h−1 | [27 ln(3) − 32 ln(2)] h−1 8 | [8 ln(2) − 3 ln(3)] h−1 2
h0f 0 | h0 2τ | h0 4τ | h0 2τ
+1 h+1f | [1.038 + 3 ln(2πfhτ )] h+1 2τ 2 4π | [24 ln(2) − 9 ln(3)] h+1 2τ 2 8π | 5 [0, 964 + ln(πτfh)] h+1 2τ 2 6π
+2 h+2f | 3h+2fh 4π 2τ 2 | 3h+2 8π 2τ 3 | 5h+2fh 6π 2τ 2
Drift: y(t) = D1t | 1 D² 2 τ 1 2 | 1 D² 2 τ 1 2 | 0

### 5.3 Drift removal and variance insensitive to drifts

1. Estimate the slope of the linear frequency drift by clicking on the button and note the drift parameter ‘degree 1’ in the ‘Drift coefficients’ section of the left window.
2. Is it compatible with the drift estimation obtained from the ADev asymptote?
3. Plot the Allan deviation of HM without drift.ykt.
4. Estimate the τ

1/2
coefficient and convert it into the corresponding noise level. What do you observe?
5. in a new frame, reload HM minute.xtt and convert it into frequency data.
6. Plot the Hadamard deviation of these frequency data (change the Deviation type in the left window).
7. Estimate the τ

1/2
coefficient and convert it into the corresponding noise level. What do you observe?
8. What do you think of the Allan variance as a tool for estimating drifts?
9. Is the drift removal method recommended?

## 6 Analysis of the file VCO 1m3.xtt

- Clock: VCO
- Data: time errors
- Sampling period: 1 ms
- Number of samples: 200 000

### 6.1 Preliminary observations

Observe VCO 1m3.xtt and transform it into frequency deviation data.

### 6.2 Allan variance vs Modified Allan variance

1. Plot the Allan deviation of the data.
2. Determine the power law asymptotes.
3. Estimate the coefficients of the power laws.
4. Calculate the corresponding noise levels of the PSD.
5. Perform the same calculation with the Modified Allan deviation.

What is the advantage of this variance? Estimate carefully the white PM level as well as the flicker PM level.

## 7 Analysis of a three-cornered system

Unfortunately, the Graphical User Interface is not available for this section and the study must be conducted by using command lines (sorry for mouse-click fans!).

- Clock: 3 Cryogenic Sapphire Oscillators (A, B and C)
- Data: frequency deviation samples
- Sampling period: 1 s
- Number of samples: 469 999
- Measuring device: K&K (Lange-Electronic GmbH)
- Files:

KnK AB.ykt: comparison of B versus A (y¯B − y¯A) KnK BC.ykt: comparison of C versus B (y¯C − y¯B) KnK CA.ykt: comparison of A versus C (y¯A − y¯C)

### 7.1 Preliminary observations

Observe the Allan deviation of these 3 files by using SigmaTheta:
SigmaTheta KnK AB.ykt KnK AB.adev
What do you think of the stability of the CSOs A, B and C?

### 7.2 Using the Groslambert Covariance

1. Compute the Groslambert Deviation (square root of the Groslambert Covariance) of CA and AB and store the result in a file (e.g. KnK A.gcod):
GCoDev KnK CA.ykt KnK AB.ykt > KnK A.gcod
2. Observe the results:
cat KnK A.gcod
What is the sign of the GCOD? Why?
3. Compute the Groslambert Deviation of AB and BC and store the result in a file (e.g. KnK B.gcod).
4. Compute the Groslambert Deviation of BC and CA and store the result in a file (e.g. KnK C.gcod).
5. Observe the stability of each clock on the same graph and store the result in a file (e.g. KnK ABC.gcod):
DevGraph KnK ABC.gcod -KnK A.gcod -KnK B.gcod -KnK C.gcod
(the dash “-” before a file name causes DevGraph to take the opposite of the data from this file).
6. What is the meaning of the negative CoDeviations (e.g. C at τ = 10⁵

and 2 · 10⁵
s).

The Groslambert Deviations can also be computed all
at once.
7. You can also type directly:


3CorneredHat KnK AB.ykt KnK BC.ykt KnK CA.ykt KnK ABC.gcod
(it could take a while. . . ).
8. The different colored areas correspond to the uncertainty domains for each clock stability. Which clock (red, green or blue) is the most stable at τ = 10²
s?
9. Same question at τ = 10⁴
s? What is the 95%
confidence interval of the ADEV estimate of the red clock? What is your conclusion regarding this clock?

## Resources

SigmaTheta is a collection of numerical programs for
time and frequency metrology. It is free software, you
can redistribute it and/or modify it under the terms of
the CeCILL License. It may be downloaded from the following git repository:
git clone https://gitlab.com/fm-ltfb/SigmaTheta

Contributors are welcome!
If you intend to contribute, do not hesitate to contact Franc¸ois Vernotte <francois.vernotte@femto-st.fr>
or Franc¸ois Meyer <fmeyer@obs-besancon.fr>.

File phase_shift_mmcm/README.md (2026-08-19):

# Qualification and correction of the phase shifts of the MMCM

In the VCXO-less implementation of White Rabbit, the oscillators internal
to the FPGA must be fine tuned to track the reference signal (main oscillator),
and the helper oscillator must track the main oscillator to generate a constant
beatnote.

The MMCMs in the Artix7 FPGA use a phase stepping mechanism: periodic phase $\phi$
increments induce a phase drift $df=\phi/(2\pi\cdot t)$ acting as fine frequency
tuning of the MMCM. However, the phase is not behaving as expected: this directory
provides the tools for mapping phase increments, and correct their unexpected 
behaviour.

See <a href="https://docs.amd.com/v/u/en-US/xapp589-VCXO">Xilinx application note XAPP589</a>
for their PICXO implementation.

Wherever a "Phase Station" is referred to, the instrument is the 
<a href="https://www.miles.io/PhaseStation_53100A_user_manual.pdf">Microchip 53100A</a>
from John Miles.

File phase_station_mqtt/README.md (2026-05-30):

# Controlling the Microchip 53100A Phase Noise Analyzer (aka Phase Station) for qualifying the White Rabbit link

## Principle

The Microchip 53100A Phase Station is provided with a javascript interpreter to automate
data acquisition. Using the blocking MQTT Publish/Subscribe calls, the acquisition is
synchronized with a Python script assessing the state of the White Rabbit node and
controlling the start of data collection. The Phase Station stores the records on the
MS-Windows hard disk for post-processing. A MQTT server (``broker``) is assumed to be
accessible on the same subnet than the Phase Station and the PC controlling the White
Rabbit board, possibly on the same latter GNU/Linux computer. In our examples, the
broker is running on a computer with IP 192.168.1.170.



## Setup

From the MQTT <a href="https://mosquitto.org/download/">repository</a> download
the MS-Windows version of Mosquitto clients and install on the MS-Windows computer
controlling the phase station since we are using a ping-pong scheme to sequence the
Phase Station acquisition and White Rabbit node behaviour control.

## Using the phase station for automated measurements with Mosquitto MQTT

The 53100A Phase Noise Analyzer allows the cration of custom Javascript scripts runnable 
from the TimeLab GUI to automate the opperation of the phase station. This repository
contains an example of automated repeated measurement, synchronized via MQTT with the 
DUT's host computer.

In this example, we repeat absolute phase measurements of an auxiliary White Rabbit clock, 
and relock the White Rabbit softPLL between each aquisition. The phase station is 
controled by <a href="phase_station_script_example.js">phase_station_script_example.js</a>
whose task is to launch and save acquisitions, while the White Rabbit device is controlled 
by <a href="wr_host_script_example.py">wr_host_script_example.py</a> whose task is to 
reset and relock the softPLL.

The two script are synchronized via MQTT and their parallel execution can be sumarized as:

| | phase station control | white rabbit control |
|:-:|:---:|:---:|
| 1 | wait MQTT | relock softPLL |
| 2 | get MQTT | send MQTT |
| 3 | acquire phase data  | wait MQTT |
| 4 | send MQTT | get MQTT |
| 5 | loop to step 1 | loop to step 1 |

## The 53100A Phase Noise Analyzer is not made for absolute phase measurments

The phase station is a *noise* analyzer and does not claim the ability to perform 
absolute phase measurements, and can introduce offset error of $\pm 1.3$ ns and 1.5 ps. 
This behavor is descibed in <a href="phase_station_indeterminism_quirks.pdf">phase_station_indeterminism_quirks.pdf</a>.

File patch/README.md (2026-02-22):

## Synthetize White-Rabbit for the Litex Acorn Baseboard Mini

We assume we are in this ``patch/`` subdirectory of the ``wr_acorn`` repository in the following command sequence. 

We assume that ``sudo apt install libncurses-dev libncurses5-dev libreadline-dev `` are installed.

### TL;DR;

With ACORN and M2SDR's JTAG both connected.

Note the M2SDR UART is hacked through (TP1/TP2) on m2sdr -> (J11.1/J11.2) on baseboard-mini.

#### ACORN CLE-215+

```bash
make acorn
openFPGALoader -b litex-acorn-baseboard-mini --cable ft4232 --cable-index 0 --freq 30000000 acorn_wr_ref_top.bit
screen /dev/ttyUSB2 115200,-cstopb
```
#### M2SDR

```bash
make m2sdr
openFPGALoader -b litex-acorn-baseboard-mini --cable ft4232 --cable-index 1 --freq 30000000 m2sdr_wr_ref_top.bit
screen /dev/ttyUSB6 115200,-cstopb
```

### 0. Compile the softcore firmware
```sh
git clone --recursive https://gitlab.com/ohwr/project/wrpc-sw
cd wrpc-sw
```

edit ``scripts/kconfig/lxdialog/check-lxdialog.sh`` according to ``https://gitlab.com/ohwr/project/wrpc-sw/-/issues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`` (removing the exit 1 statement on line 56 of 
``scripts/kconfig/lxdialog/check-lxdialog.sh``)

```
make menuconfig
```

select ``Architecture = riscV`` and ``Target Platform = Generic WR Node with 16-bit PCS/PHY``

Then, using either the binary toolchain found on the <a href="https://gitlab.com/ohwr/project/wrpc-sw/-/wikis/uploads/9f9224d2249848ed3e854636de9c08dc/riscv-11.2-small.tgz">CERN</a>
OHWR web site, but preferably generating using Crosstools-NG, include the cross-compiler in the path and cross-compile

```
export PATH=$HOME/WR/riscv-11.2-small/bin:$PATH  # adapt to you directory layout
make
```

The resulting ``wrc.bram`` will be needed later to synthesize the bitstream, assuming its location
will be ``wr-cores/bin/wrpc/wrc_phy16_direct_dmtd.bram`` (see below).

Go back to this directory: ``cd ..``

### 1. Get the sources
```sh
git clone --recursive https://gitlab.com/ohwr/project/wr-cores.git
cd wr-cores
git checkout mle/upstream/zc706
git checkout 1de3f69cdffaad0003f8e6dfd2fb4d8919574964
```

### 2. Apply the patch
```sh
git apply ../wr_acorn.patch
```
or 
```sh
patch -p1 < ../wr_acorn.patch
```
or 

### 3. Synthesize the gateware
Make sure ``hdlmake`` is installed (``pip install --user hdlmake`` or execute ``python3 ./setup.py install --user`` 
from a clone of https://gitlab.com/ohwr/project/hdl-make) and that Vivado is in the ``PATH`` 
(e.g. ``source /opt/Xilinx/Vivado/2022.2/settings64.sh`` -- tested with Vivado 2019.1, 2021.1, 2022.2 and 2024.2)

```sh
cd syn/acorn_ref_design
cp ../../../wrpc-sw/wrc.bram ../../../wr-cores/bin/wrpc/wrc_phy16_direct_dmtd.bram
hdlmake
make -i
```
Do not be concerned with ``hdlmake`` stating that
```
INFO    action.py:141: build_file_set() not parseable: .../wr_acorn/patch/wr-cores/top/acorn_ref_design/acorn_wr_ref_top.bmm
INFO    action.py:141: build_file_set() not parseable: .../wr_acorn/patch/wr-cores/top/acorn_ref_design/acorn_wr_ref_top.xdc
```
but notice that the patch did create a file ``syn/acorn_ref_design/bitstream.tcl`` including the statement
```
set_property SEVERITY WARNING [get_drc_checks REQP-49]
```
Since ``make clean`` will delete all TCL scripts, the newly generated ``bitstream.tcl`` will miss this option, leading to a failure
to synthesize the bitstream. Thus, avoid ``make clean``, or at least include the ``bitstream.tcl`` manually in the ``syn/acorn_ref_design``
to avoid ``Makefile`` from overwriting and deleting the mandatory option.

If trying to relaunch a synthesis after removing the ``bitstream`` file, the ``bitstream.tcl`` must include ``reset_run synth_1`` before ``launch_runs impl_1 -to_step write_bitstream``.

### 4. Flash the bitstream
```sh
openFPGALoader -c ft4232 -b litex-acorn-baseboard-mini -f ./acorn_wr_ref.runs/impl_1/acorn_wr_ref_top.bit
```

### 5. Connect to White-Rabbit UART
```sh
minicom -D /dev/ttyUSB2
```

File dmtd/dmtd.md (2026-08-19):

# Digital Mixer Time Difference

The DMTD function is to measure fine timing of digital clocks. It does so by (sub)sampling the input clock with a frequency shifted clock to time-strech the input clock into a low-frequency signal which can be measured with a great resolution relative to it's period, the output of the DMTD is a flow of time stamps (phase tags) of the stretched rising edges.

The *D*DMTD uses two DMTDs and takes the difference of the phase tags to output the relative phase of two clocks:

ddmtd schematic

Here, to study this DDMTD phase meter we first focus on the simpler DMTD.

### Notations
The frequency ratio between the measured clock and the sampling clock (also called pivot or dmtd clock) is set as 2^N/(2^N - 1) with N = 14 unless specified otherwise.
This means that the frequency difference (named beatnote) is 1/2^N times the measured clock frequency, this beatnote also correspond to the output rate the DMTD.

The output phase tags counts time in cycles of the pivot clock, in a noiseless systeme, they are each spaced of 2^N cycles.
The phase resolution is then of N bits.

For example when measuring a 62.5 MHz clock with N=14, we get phase tags at the rate of 62.5e6/2^14 ~= 3.814 kHz with a resolution of 16e-9/2^14 ~= 1 ps.

## Aliasing

Since the dmtd is subsampling the input clock, it aliases high frequency noise in the small bandwith of it's low-frequency output (1.9 kHz bandwith in default white rabbit).

This can be demonstrated by feeding a clock with a single spure of noise at a variable offset frequency and observing how this spur is folded into the dmtd's output:
frequency of the spur on the output in function of its frequency at the input

This hints that all the noise is conserved and folded (2^N times) in the dmtd's bandwith leading to a 2^N times higer floor noise with the same noise power.
We observe that it is, in fact, not the case: by feeding the dmtd a clock with white gaussian phase noise and measuring the noise at the output we get this square root response:
dmtd stddev at the output in function of the stddev at the input

This nonlinear behavior can't be explained by the (linear) sampling, this suggest there is a non-linear filtering action of the deglicher.

## Gliches

Because of clocks jitter and/or metastabilities (we have yet to investigate which is dominant and wether they have distinct effects), the output of the sampling flip-flop contains many transitions for each ideal streched clock transitions.

dmtd gliches
ILA capture of the sampled clock.

The deglicher process this waveform and computes the phase tag of the true transition. Multiple deglichers algorithms have been proposed and evaluated ([Tom's thesis](https://gitlab.com/ohwr/project/white-rabbit/-/wikis/uploads/6a357829064b9e27a46fbce4cb4398b4/mgr.pdf)) empiricaly we find that the "bit median" produce the less noisy outputs but we lack a rigorous understanding of why.

The bit median deglicher assume that the gliches are like random independant "flip" errors on the true clean rising edge of the streched clock, following some constant (over time) distribution around this true rising edge.
It then compute and output the phase tag such that there is as many "up" gliches before the phase tag as "down" glitches after the phase tag.
This is exactly the same as a doing least square fit of the gliched signal with the ideal step and outputting the time of the fitted step's rising edge.
This kind of fit can be realized in many ways: this bit median / cross-correlation / convolution, these are all the same computation, of which the "bit median" algorithm is just a very efficient FPGA implementation. 

The length of this glichy window is directly proportional to the input clock jitter:
dmtd average gliches length is proportional to input jitter

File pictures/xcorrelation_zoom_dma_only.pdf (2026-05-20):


time (s) x10 -2.5 | -7 +2.5 0

cross-correlation (a.u.)

-5 | +5

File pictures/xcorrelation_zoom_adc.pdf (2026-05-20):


0
-2 | -1-3 | +2 | +3+1 | +4

cross-correlation (a.u.)

time (s) x10-7

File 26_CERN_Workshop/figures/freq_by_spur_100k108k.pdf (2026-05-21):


Dominant frequency in dmtd output by spur offset

main freq in DMTD (Hz)

spur offset from carrier (Hz)

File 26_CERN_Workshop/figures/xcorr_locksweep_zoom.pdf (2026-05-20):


cross-correlation (a.u.)

0
-5 | -2.5 | time (s) x10-7 | 2.5 | 5 | 7.5

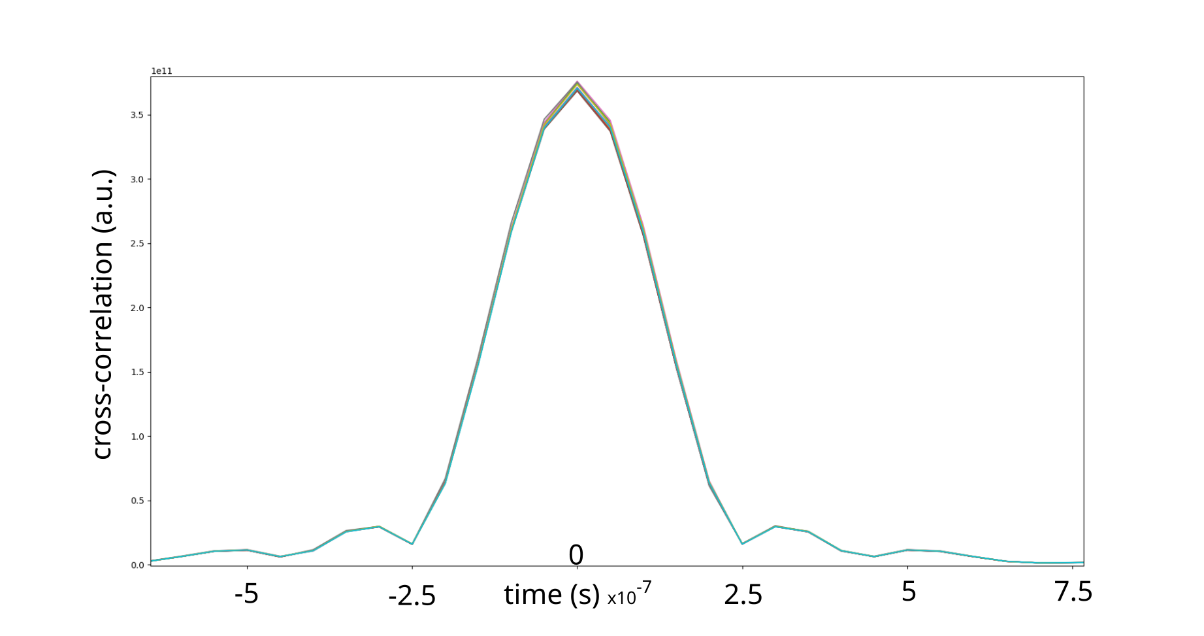
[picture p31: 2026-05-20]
26_CERN_Workshop/figures/xcorr_locksweep_zoom.png

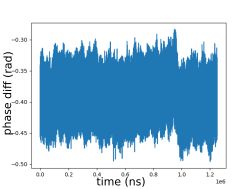
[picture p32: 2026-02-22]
pictures/phase_diff_synth.png

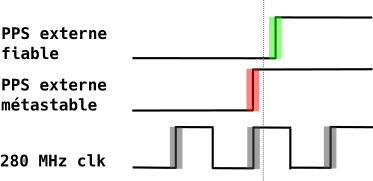
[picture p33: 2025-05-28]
25_CERN_Workshop/figures/pps_waveform.png

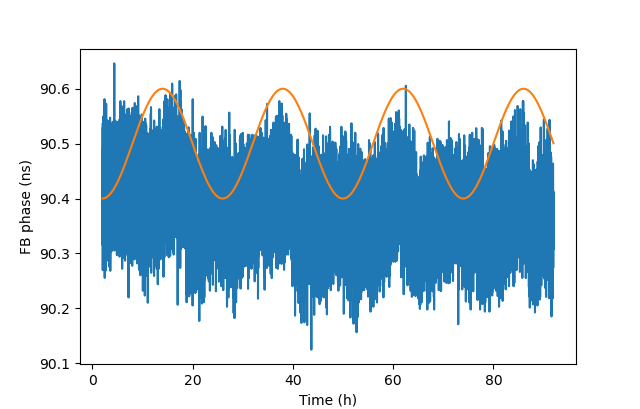
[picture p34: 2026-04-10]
26_CERN_Workshop/figures/locksweep_phase_setpoint.png

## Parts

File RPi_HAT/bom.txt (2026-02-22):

qty	Mouser reference	price/1	description
5 	798-FH12-16S-05SH55	1.36	Hirose FH12-16S-0.5SH
5 	200-SFPC-SL		2.14	Cage SFP (Farnell 2856825)
5 	571-13670731		1.74	connecteur SFP (Farnell 2112385)
5 	523-MDT275M03001	1.61	M2 M-key
100 	MCS04020C1002FE000 	0.01	10k 0402
100	MEASA105CB5226MFNA01 	0.067	22u 0402
100 	594-MCS04020C4701FE0 	0.02	4k7 0402
100	875-MI0603K300R-10	0.058	ferrite 0603
15	621-DMG1012TQ-7		0.079	MOSFET
5	771-PCA9306DC1Z 	0.79	PCA9306
5	863-LM1117MPX-18NOPB	0.49	LM1117-1.8
5	595-TPS564242DRLR 	0.421	TPS564242DRLR
20	652-CR0402FX-3651GLF	0.004	3k6 0402
20	594-MCS04020C2211FE0	0.089	2k2 0402
100	581-0805ZC106KAT4A 	0.109	10u 0805
100	603-CC402KRX5R6BB105	0.027	1u 0402
100	0402X7R104KT7AT 	0.085	100n 0402
100	80-C0402C101K3RAUTO	0.026	100p 0402
100	652-CR0402-JW-682GLF	0.006	6k8 0402
100	603-RC0402FR-7D33RL 	0.006	33 0402
100	652-CR0402FX-3002GLF	0.006	30k 0402
100	RG1005P-471-D-T10   	0.009	470 0402
20	603-AC0402FR-7D200KL	0.012	200k 0402
5	70-IHLP2020CZR1R5M5A	0.86	1.5uH
5	200-SSW10301GD 		0.903	connecteur 2x03
20	603-RC0402FR-07137KL	0.005	137k 0402
5       710-687712050002        2.54    50 mm long flat cable

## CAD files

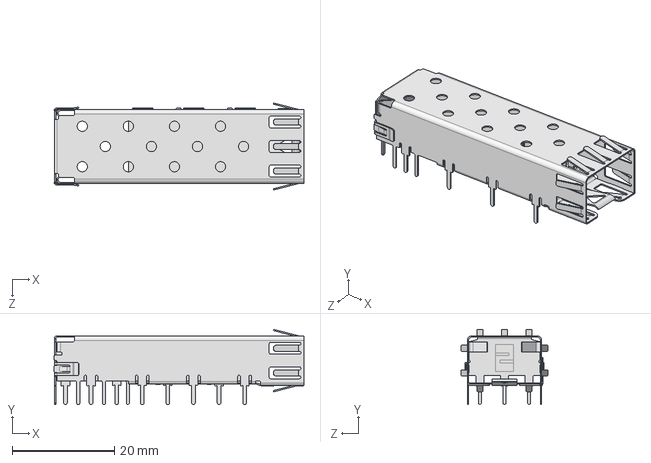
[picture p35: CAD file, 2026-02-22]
RPi_HAT/SFPC-SL.STEP
48.8 x 14.7 x 17.0 mm

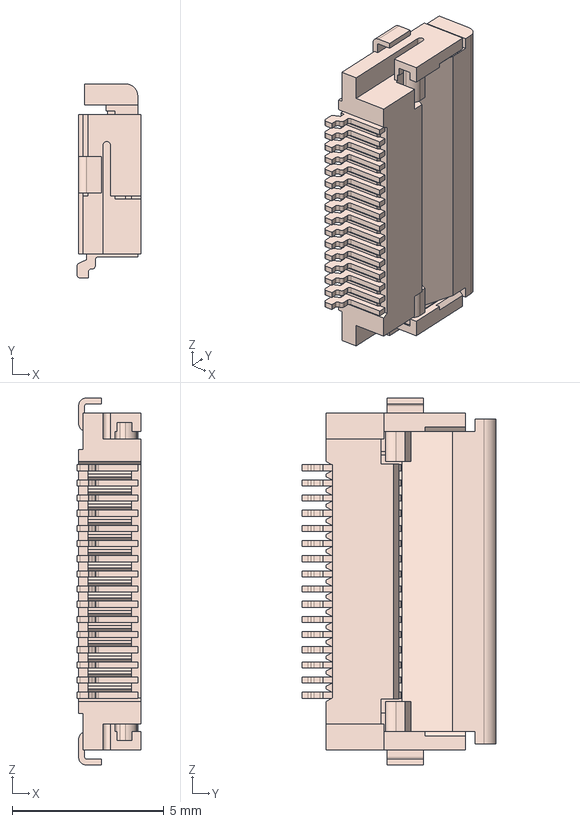
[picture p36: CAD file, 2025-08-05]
RPi_HAT/FH12-16S-0.5SH.stp
2.10 x 6.40 x 12.1 mm

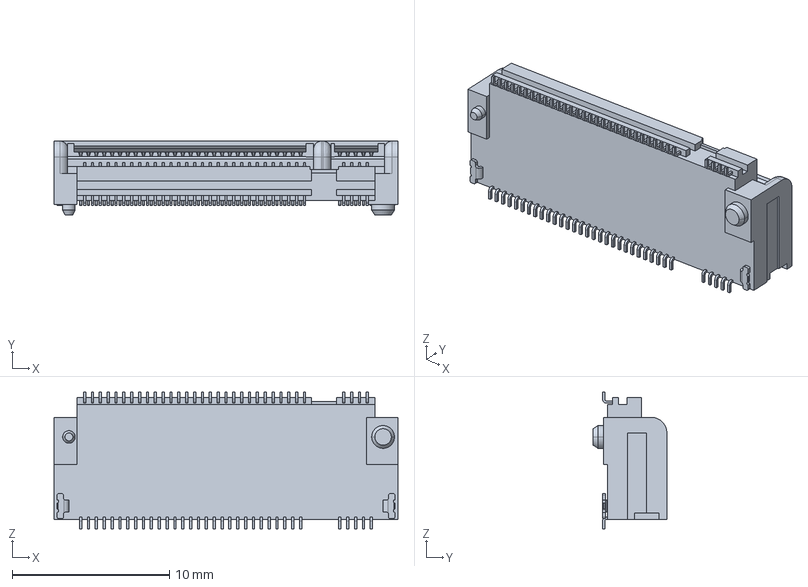
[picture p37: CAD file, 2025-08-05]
RPi_HAT/c-1-2199230-4-b3-3d.stp
21.9 x 4.70 x 8.70 mm

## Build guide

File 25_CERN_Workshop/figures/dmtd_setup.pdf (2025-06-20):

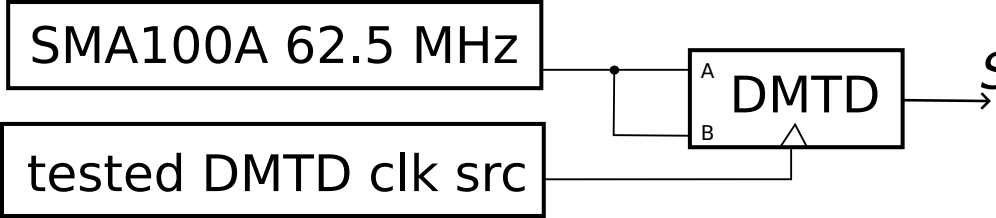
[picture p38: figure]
DMTD; SMA100A 62.5 MHz; tested DMTD clk src

S
φ

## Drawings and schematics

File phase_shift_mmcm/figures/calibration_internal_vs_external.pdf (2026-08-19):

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

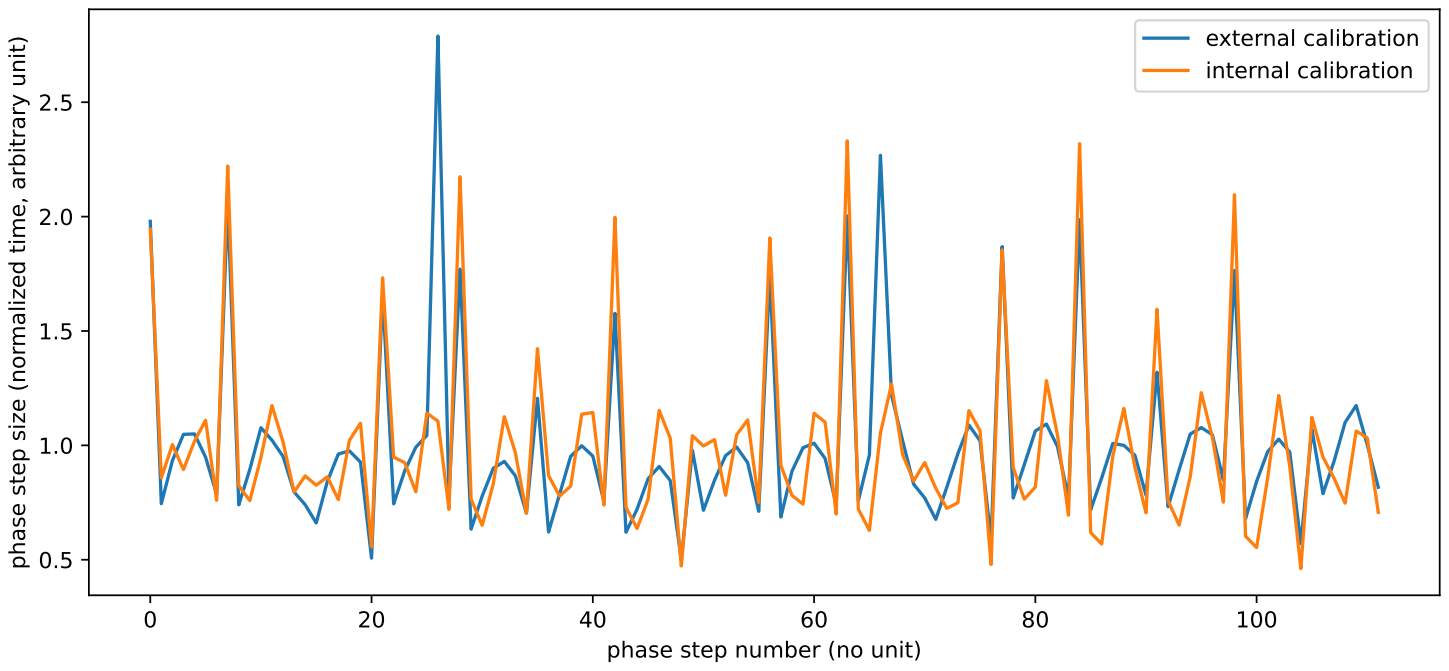
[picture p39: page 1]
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

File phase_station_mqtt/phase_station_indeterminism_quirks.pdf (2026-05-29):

# Original Goal: Finding PLLs lock setpoint possibilities

- PLLs multiply the input by P to VCO frequency and divide the VCO by Q to the output (possibly with a counter)
- If this counter only takes into account the VCO clock (and not the input), we expect Q possible setpoints.
- If the PLL is smarter and starts the counter at an input clock edge, it can reduce this to Q/P possible setpoints.

## Phase station

## PLL (x 10 / 50)

## PLL (x 62.5 / 10)

## Signal generator

10 MHz | 12.5 MHz

### 62.5 MHz

### 12.5 MHz

## ref

## DUT

## RST

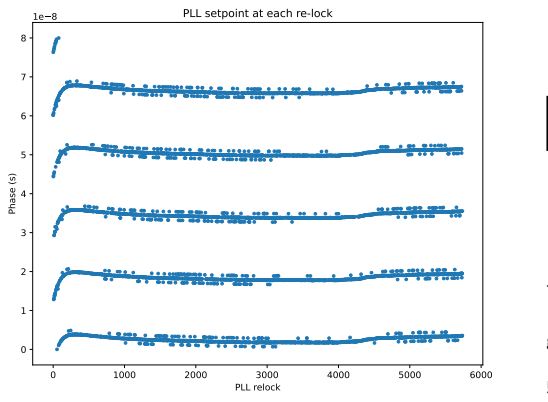
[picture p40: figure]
PLL relock; Phase (s); PLL setpoint at each re-lock

To find what kind of PLLs are implemented in our FPGA we measure the setpoint over multiple resets. The reseted PLL generates 12.5 MHz from 62.5 MHz, with a VCO at 625 MHz. Depending on the PLL implementation, we expect 50 or 5 possible setpoints, respectively 1.6 ns or 16 ns apart.

# Finding PLLs lock setpoint possibilities

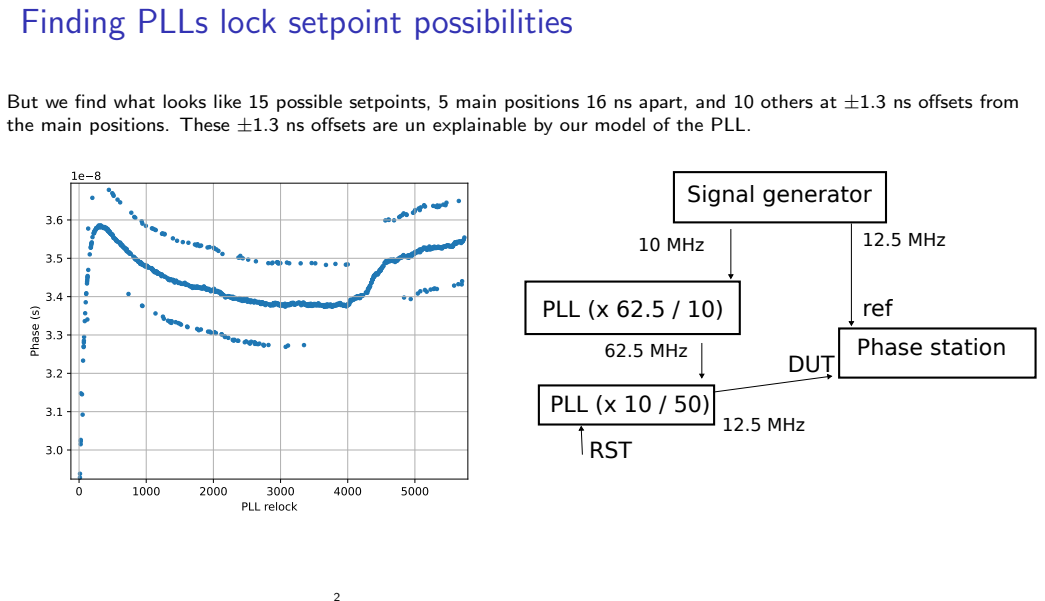
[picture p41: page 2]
PLL relock; Phase (s); Phase station; PLL (x 10 / 50); PLL (x 62.5 / 10); Signal generator; 10 MHz; 12.5 MHz; 62.5 MHz; ref; DUT; RST 2

But we find what looks like 15 possible setpoints, 5 main positions 16 ns apart, and 10 others at ±1.3 ns offsets from
the main positions. These ±1.3 ns offsets are un explainable by our model of the PLL.

# Checking the determinism of the 53100A Phase Noise Analyzer

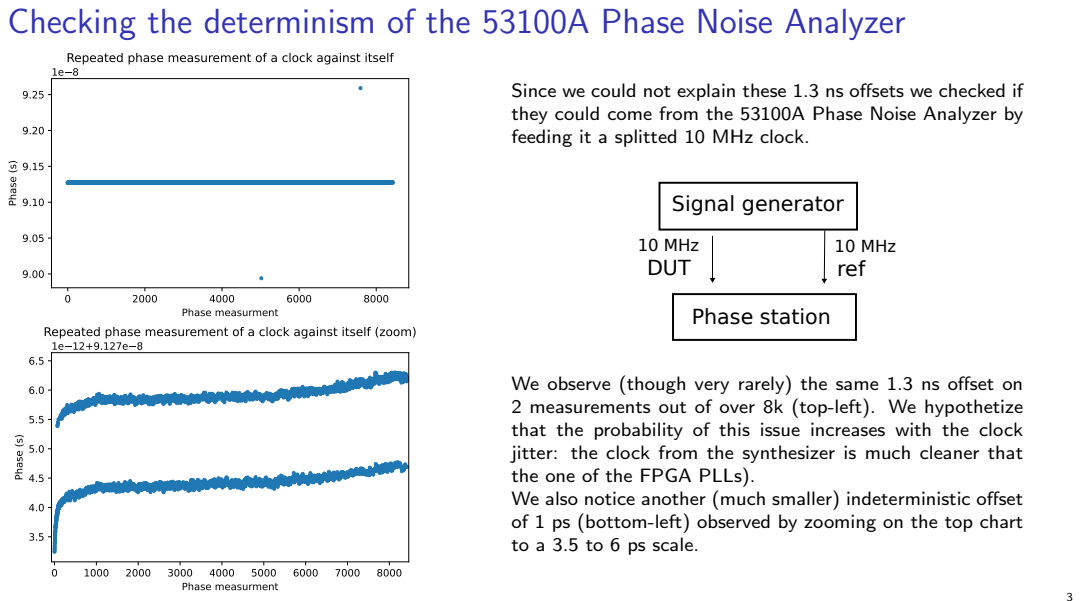
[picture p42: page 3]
Phase measurment; Phase (s); Phase station; Signal generator; 10 MHz; DUT; ref

Repeated phase measurement of a clock against itself

Since we could not explain these 1.3 ns offsets we checked if
they could come from the 53100A Phase Noise Analyzer by
feeding it a splitted 10 MHz clock.

10 MHz We observe (though very rarely) the same 1.3 ns offset on

Repeated phase measurement of a clock against itself (zoom)

2 measurements out of over 8k (top-left). We hypothetize
that the probability of this issue increases with the clock
jitter: the clock from the synthesizer is much cleaner that
the one of the FPGA PLLs).
We also notice another (much smaller) indeterministic offset
of 1 ps (bottom-left) observed by zooming on the top chart
to a 3.5 to 6 ps scale.

# Checking the determinism of the 53100A Phase Noise Analyzer

1 | const path =" .../ Documents / phase_meas ";
2 | var acq_num = 0;
4 | function EventRunScript () {
5 | acq_num = 0;
6 | run_acq () ;
7 | }
9 | function run_acq () { | // wait for PLL relock
10 | if (! FileExecuteWait ("c :\\...\\ mosquitto_sub . exe ", " -→
,→h 192.168.1.170 -t reset_done -C 1")) {
11 | ScriptEnd () ;
12 | }
13 | AcqClearParams () ;
14 | // Set params with auto generated config
15 | // [...]
16 | AcqStartAcquisition (" Microchip 53100 A ... ", true );
17 | }
19 | function EventAcqDone () {
20 | FileSave (path , " save_ " + acq_num + ".tim "); ++ acq_num ;
21 | // Send end of measure event to reset the pll
22 | if (! FileExecute ("c :\\...\\ mosquitto_pub . exe ", " -h →
,→192.168.1.170 -t measure_done -m acq_done ") ) {
23 | ScriptEnd () ;
24 | }
25 | FileCloseAllPlots () ;
26 | run_acq () ;
27 | }

To run these experiments we made this script that is synchronised via MQTT with the computer that hosts the FPGA.
This script waits for a MQTT message signaling that the PLL is locked, then starts the acquisition. When the acquistion is complete it sends a MQTT message, allowing the FPGA to reset the PLL, and goes back to waiting the lock for the next acquisition.

We also tried to make one long acquisition but the phase station doesn’t support a clock going off and on again.

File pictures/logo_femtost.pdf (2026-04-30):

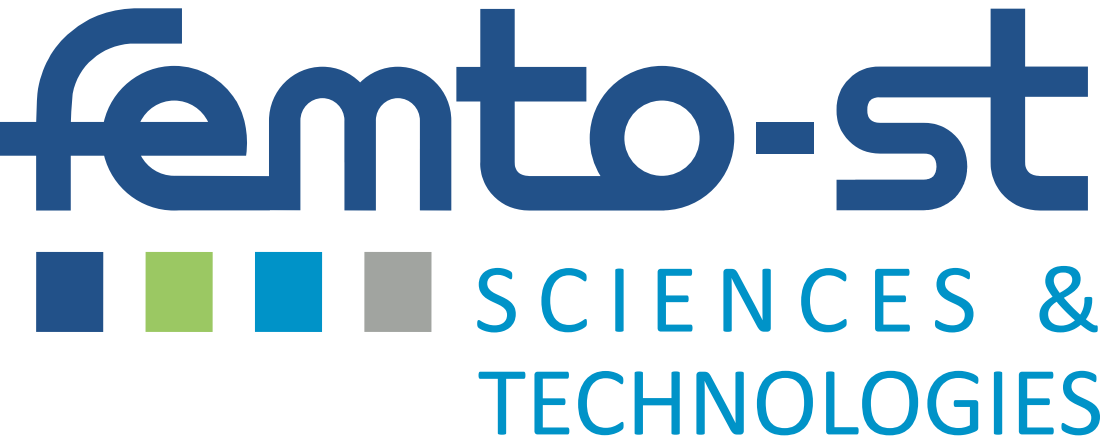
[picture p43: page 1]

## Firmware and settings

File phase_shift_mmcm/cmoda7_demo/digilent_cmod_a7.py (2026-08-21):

#!/usr/bin/env python3

#
# This file is part of LiteX-Boards.
#
# Copyright (c) 2021 Michael T. Mayers <michael@tweakoz.com>
# SPDX-License-Identifier: BSD-2-Clause

from migen import *
from migen.genlib.resetsync import *

from litex.gen import *


from litex_boards.platforms import digilent_cmod_a7

from litex.soc.cores.clock import *
from litex.soc.integration.soc import *
from litex.soc.integration.soc import SoCRegion
from litex.soc.integration.builder import *
from litex.soc.cores.led import LedChaser
from litex.soc.interconnect import wishbone

from litex.soc.integration.soc import colorer
from litex.build.generic_platform import IOStandard, Pins

from gateware.self_calib_picxo_wr_clock_assembly import WRClocking 

# CRG ----------------------------------------------------------------------------------------------

class _CRG(LiteXModule):
    def __init__(self, platform, sys_clk_freq):
        self.rst    = Signal()
        self.cd_sys = ClockDomain()
        self.cd_ctrl = ClockDomain()

        # # #

        # Clk/Rst.
        clk12 = platform.request("clk12")
        rst   = platform.request("cpu_reset")

        # PLL.
        self.pll = pll = S7MMCM(speedgrade=-1)
        self.comb += pll.reset.eq(rst | self.rst)
        pll.register_clkin(clk12, 12e6)
        pll.create_clkout(self.cd_sys, sys_clk_freq)
        pll.create_clkout(self.cd_ctrl, 100e6)
        platform.add_false_path_constraints(self.cd_sys.clk, pll.clkin) # Ignore sys_clk to pll.clkin path created by SoC's rst.

# AsyncSRAM ------------------------------------------------------------------------------------------

class AsyncSRAM(LiteXModule):
    def __init__(self, platform, size):
        addr_width = size//8
        data_width = 8
        self.bus = wishbone.Interface(data_width=data_width,adr_width=addr_width)
        issiram = platform.request("issiram")
        addr = issiram.addr
        data = issiram.data
        wen = issiram.wen
        cen = issiram.cen
        oe = issiram.oe
        ########################
        tristate_data = TSTriple(data_width)
        self.specials += tristate_data.get_tristate(data)
        ########################
        chip_ena = self.bus.cyc & self.bus.stb & self.bus.sel[0]
        write_ena = (chip_ena & self.bus.we)
        ########################
        # external write enable,
        # external chip enable,
        # internal tristate write enable
        ########################
        self.comb += [
            cen.eq(~chip_ena),
            wen.eq(~write_ena),
            tristate_data.oe.eq(write_ena),
            oe.eq(tristate_data.oe),
        ]
        ########################
        # address and data
        ########################
        self.comb += [
            addr.eq(self.bus.adr[:addr_width]),
            self.bus.dat_r.eq(tristate_data.i[:data_width]),
            tristate_data.o.eq(self.bus.dat_w[:data_width])
        ]
        ########################
        # generate ack
        ########################
        self.sync += [
            self.bus.ack.eq(self.bus.cyc & self.bus.stb & ~self.bus.ack),
        ]
        ########################


def addAsyncSram(soc, platform, name, origin, size):
    ram_bus = wishbone.Interface(data_width=soc.bus.data_width)
    ram     = AsyncSRAM(platform,size)
    soc.bus.add_slave(name, ram.bus, SoCRegion(origin=origin, size=size, mode="rw"))
    soc.check_if_exists(name)
    soc.logger.info("ISSIRAM {} {} {}.".format(
        colorer(name),
        colorer("added", color="green"),
        soc.bus.regions[name]))
    setattr(soc.submodules, name, ram)

# BaseSoC ------------------------------------------------------------------------------------------

class BaseSoC(SoCCore):
    def __init__(self,  variant="a7-35",
        toolchain       = "vivado",
        sys_clk_freq    = 100e6,
        with_spi_flash  = False,
        calib_file      = None,
        **kwargs):

        platform = digilent_cmod_a7.Platform(variant=variant, toolchain=toolchain)

        # CRG --------------------------------------------------------------------------------------
        self.crg = _CRG(platform, sys_clk_freq)

        # SoCCore ----------------------------------------------------------------------------------
        SoCCore.__init__(self, platform, sys_clk_freq, ident="LiteX SoC on Digilent CmodA7", **kwargs)

        # Async RAM --------------------------------------------------------------------------------
        addAsyncSram(self,platform,"main_ram", 0x40000000, 512 * KILOBYTE)

        # SPI Flash --------------------------------------------------------------------------------
        if with_spi_flash:
            from litespi.modules import MX25U3235F
            from litespi.opcodes import SpiNorFlashOpCodes as Codes
            self.add_spi_flash(mode="4x", module=MX25U3235F(Codes.READ_1_1_4), with_master=True)

        # DCO
        ####################

        frac_size = 24
        int_size = 8

        platform.add_extension([
            ('clk_in',  0, Pins('j2:21'), IOStandard('LVCMOS33')),
            ('clk_out', 0, Pins('j2:11'), IOStandard('LVCMOS33')),
            ('dbg',     0, Pins('j2:17'), IOStandard('LVCMOS33')),
        ])

        clk_in = Signal()
        clk_out = Signal()
        self.comb += clk_in.eq(platform.request('clk_in'))
        self.comb += platform.request('clk_out').eq(clk_out)
        platform.add_period_constraint(clk_in, 1e9/100e6)
        
        self.dco_rate = CSRStorage(size=frac_size)
        self.dco_csr = CSRStorage(fields=[
            CSRField("reset", size=1, offset=0),
            CSRField("sigmadelta_en", size=1, offset=1),
            CSRField("nonlin_en", size=1, offset=2),
            CSRField("start_calib", size=1, offset=3),
            CSRField("start_no_calib", size=1, offset=4),
        ])
        
        self.dco_stat = CSRStatus(fields=[
            CSRField("calib_done", size=1, offset=0),
            CSRField("doing_calib", size=1, offset=1),
            CSRField("dmtd_tag", size=16, offset=16),
        ])

        self.clocking = WRClocking(platform, calib_file=calib_file, frac_size=frac_size, int_size=int_size)
        
        self.comb += [
                self.clocking.clk100_in.eq(clk_in),
                clk_out.eq(self.clocking.tunned_clk),

                #platform.request('dbg').eq(self.clocking.sigmadelta.dither_en),

                self.clocking.freq_cmd.eq(self.dco_rate.storage),
                self.clocking.reset.eq(self.dco_csr.fields.reset),
                self.clocking.sigmadelta_en.eq(self.dco_csr.fields.sigmadelta_en),
                self.clocking.linearize_en.eq(self.dco_csr.fields.nonlin_en),
                self.clocking.start_calib.eq(self.dco_csr.fields.start_calib),
                self.clocking.start_no_calib.eq(self.dco_csr.fields.start_no_calib),
                
                self.dco_stat.fields.calib_done.eq(self.clocking.calib_done),
                self.dco_stat.fields.doing_calib.eq(self.clocking.doing_calib),
                self.dco_stat.fields.dmtd_tag.eq(self.clocking.calib.tag),
                ]




# Build --------------------------------------------------------------------------------------------

def main():
    from litex.build.parser import LiteXArgumentParser
    parser = LiteXArgumentParser(platform=digilent_cmod_a7.Platform, description="LiteX SoC on CMOD A7.")
    parser.add_target_argument("--flash",          action="store_true",      help="Flash bitstream.")
    parser.add_target_argument("--variant",        default="a7-35",          help="Board variant (a7-35 or a7-100).")
    parser.add_target_argument("--sys-clk-freq",   default=48e6, type=float, help="System clock frequency.")
    parser.add_target_argument("--with-spi-flash", action="store_true",      help="Enable memory-mapped SPI flash.")
    parser.add_target_argument("--calib-file",                               help="Calibration file for step-size linearization.")

    args = parser.parse_args()

    soc = BaseSoC(
        variant        = args.variant,
        toolchain      = args.toolchain,
        sys_clk_freq   = args.sys_clk_freq,
        with_spi_flash = args.with_spi_flash,
        calib_file     = args.calib_file,
        **parser.soc_argdict
    )

    builder_argd = parser.builder_argdict

    builder = Builder(soc, **builder_argd)
    if args.build:
        builder.build(**parser.toolchain_argdict)

    if args.load:
        prog = soc.platform.create_programmer()
        prog.load_bitstream(builder.get_bitstream_filename(mode="sram"))

    if args.flash:
        prog = soc.platform.create_programmer()
        prog.flash(0, builder.get_bitstream_filename(mode="flash"))

if __name__ == "__main__":
    main()

class BaseSoC_SIM(LiteXModule):
    def __init__(self,
                 int_size=8,
                 frac_size=24,
                 dco_rate=775680,
                 dco_dither_en=1,
                 dco_nonlin_en=1,
                 ):
        from gateware.sigmadelta import SigmaDeltaPSGen
        from gateware.nonlin_lut import NonLinearityLUT, lut_from_trace

        self.sigmadelta = SigmaDeltaPSGen(int_size=int_size, frac_size=frac_size)
        self.sd_lut = NonLinearityLUT(lut=np.array(list(map(float, open('/tmp/ss').read().split()))), int_size=int_size, frac_size=frac_size)

        self.comb += [
                self.sigmadelta.rate.eq(dco_rate),
                self.sigmadelta.sigmadelta_en.eq(dco_dither_en),
                self.sigmadelta.step_up.eq(
                    Mux(dco_nonlin_en,
                        self.sd_lut.step_up,
                        1 << frac_size,
                    )),
                self.sigmadelta.step_down.eq(
                    Mux(dco_nonlin_en,
                        self.sd_lut.step_down,
                        1 << frac_size,
                    )),
                self.sd_lut.lut_shift.eq(self.sigmadelta.lut_shift),
                self.sd_lut.sign.eq(self.sigmadelta.sign),
                ]

def sim(sd, nl, n=100000):
    from migen.sim import run_simulation

    dut = BaseSoC_SIM(dco_dither_en=sd, dco_nonlin_en=nl)

    def run():
        l = [None] * n
        p = 0
        pl = 0
        for i in range(n):
            yield
            shift = (yield dut.sigmadelta.shift)
            lut_shift = (yield dut.sigmadelta.lut_shift)
            sign = (yield dut.sigmadelta.sign)
            count = (yield dut.sd_lut.count)
            if shift:
                p += -1 if sign else 1
            if lut_shift:
                pl += -1 if sign else 1
            l[i] = (p, pl, count)
        open(f'phase_sim_{sd}_{nl}.txt', 'w').write(str(l))


    run_simulation(dut, run(), vcd_name=f'sim_{sd}_{nl}.vcd')

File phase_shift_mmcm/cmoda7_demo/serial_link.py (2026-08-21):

#!/usr/bin/env python3

import serial
import argparse
import time
import numpy as np
from matplotlib import pyplot as plt

device = '/dev/ttyUSB1'
baudrate = 115200

def ask(s, cmd):
    s.write(b'\n')
    s.flush()
    time.sleep(0.1)
    s.reset_input_buffer()
    for c in f'{cmd}\n':
        s.write(c.encode())
        print(c, end='')
        time.sleep(0.05)
    return s.read_until(b'> ').decode()

def read_lut(s, lut_addr=0xf0000000):
    r = ask(s, f'mem_read {lut_addr} {112*4}')
    print(r)
    m = np.array(sum(list(map(lambda l: list(map(lambda x: int(x, 16), l.split()[1:17])), r.split('\n')[2:-1])), start=[]))
    l = m[0::4] + 0x100 * m[1::4] + 0x10000*m[2::4] + 0x1000000*m[3::4]
    l = l / 2**24
    return l

def write_lut(s, l, lut_addr=0xf0000000):
    for i, c in enumerate(l):
        ask(s, f'mem_write {lut_addr + 4*i} {int(round(c*2**24))}')

def read_lut_map_csr_csv(filename):
    f = 'csr_base,clocking_sd_lut_mem'
    with open(filename) as file:
        r = file.read()
        for l in r.split('\n'):
            if l.startswith(f):
                return int(l.split(',')[2])

def main():
    parser = argparse.ArgumentParser()
    parser.add_argument('-D', '--device', metavar='TTY', default=device)
    parser.add_argument('--csr', metavar='CSR.csv')
    parser.add_argument('--addr', metavar='LUT_ADDR', default=0xf00000000)
    parser.add_argument('-l', '--load', metavar='CALIB_FILE')
    parser.add_argument('-d', '--dump', metavar='CALIB_FILE')
    
    args = parser.parse_args()
    
    if not args.addr:
        addr = read_lut_map_csr_csv(args.csr)
    else:
        addr = args.addr

    s = serial.Serial(args.device, baudrate=baudrate)
    if args.dump:
        lut = read_lut(s, addr)
        open(args.dump, 'w').write('\n'.join(lut))

    if args.load:
        write_lut(s, map(float, open(args.load).read().split()), addr)

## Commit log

2025-07-28 RPi5 HAT
    [FH12-16S-0.5SH.stp, RPI5-CFE-Hat.kicad_pcb, RPI5-CFE-Hat.kicad_sch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]
2025-08-19 add through holes for SMA connectors
    [RPI5-CFE-Hat.kicad_pcb, SFPC-SL.STEP]
2025-10-03 reposition 2.54 mm header connector
    [RPI5-CFE-Hat.kicad_pcb]
2025-10-15 cleanup BOM and generate inteactive BOM
    [RPI5-CFE-Hat.kicad_sch]
2025-10-27 Y axis
2025-12-02 document m2sdr dma sync
2025-12-05 add explaination for adc synchronization
2026-02-22 m2sdr: support litex m2sdr board use E22/D22 TP1/TP2 as uart
2026-05-13 temperature reading script
2026-08-19 add mmcm demo on cmoda7
    [File_001.CSV, phase_noise.csv]
2026-08-19 add mmcm phase noise README
    [digilent_cmod_a7.py]
2026-08-19 cleanup obsolete files
    [File_001.CSV, phase_noise.csv]
2026-08-19 add calibrations instructions
2026-08-19 add calibration processing script
2026-08-20 add .gitignore and fix typos
    [digilent_cmod_a7.py]
2026-08-21 add option for auto-calibration
2026-08-21 add option for auto-calibration (update README)
2026-10-26 update board
